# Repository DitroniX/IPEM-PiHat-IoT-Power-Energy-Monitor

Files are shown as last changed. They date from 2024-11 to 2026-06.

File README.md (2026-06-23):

# IPEM PiHat and IPEM PiHat Lite | ATM90E36 IoT Mains Power Energy Monitors

**Supporting STEM Electronic Internet of Things & Home Automation Technology for Smart Energy Monitoring**

DitroniX WiKi Pages (https://github.com/DitroniX/IPEM-PiHat-IoT-Power-Energy-Monitor/wiki)
DitroniX Discussions (https://github.com/DitroniX/IPEM-PiHat-IoT-Power-Energy-Monitor/discussions)
Compare DitroniX Mains Power IoT Energy Monitor Options

[**For Latest Project Updates - Click Here**](https://github.com/DitroniX/IPEM-PiHat-IoT-Power-Energy-Monitor/tree/main?tab=readme-ov-file#updates)

## Welcome to IPEM PiHat

The **IPEM PiHat** and **IPEM PiHat Lite,** are Mains AC Power Energy Monitor boards, which are designed to be used alongside Raspberry Pi, and similar single board computers.

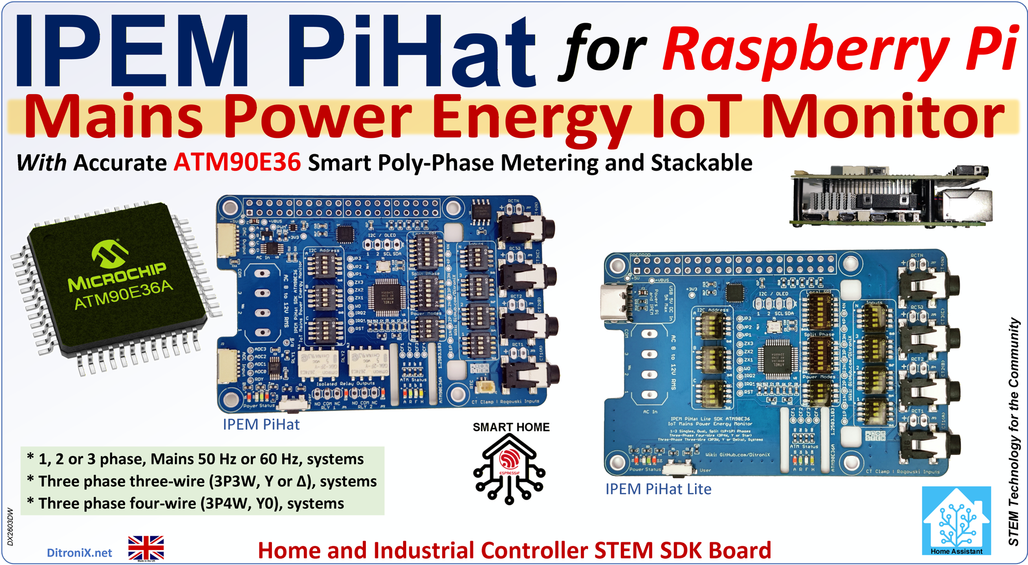
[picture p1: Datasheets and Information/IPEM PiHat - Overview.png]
IPEM PiHat


### What is a Power Energy Monitor?

A power energy monitor is a device that safely samples the [AC Voltage, and Current flow](https://github.com/DitroniX/IPEM-Plus-ESP32-C5-LoRa-LoRaWAN-IoT-Mains-Power-Energy-Monitor/wiki/What-is-a-Power-Energy-Monitor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), from one, or more, electrical phases, and from this, derives a range of accurate mains power measurements which can then be used for smart metering, or energy monitoring purposes.

These individual measurements can then be extrapolated into a range of useful real-time data such as total RMS Power, Active, Re-Active Power, Harmonic Power, Power Factor, Phase Angles, Frequency, etc.

This real-time data can then be sent via Wi-Fi or Ethernet, through to IoT Home and Industrial Energy Monitoring systems like [Home Assistant](https://www.home-assistant.io/docs/energy/).

## Variants

Two variants of IPEM PiHat are available.

 - IPEM PiHat 
	 - Full board with ATM90E36, DS3231SN RTC, Relays, 
 - IPEM PiHat Lite
	 - ATM90E36, Stackable

[Full Comparison Table.](https://github.com/DitroniX/IPEM-PiHat-IoT-Power-Energy-Monitor/wiki/Comparison-Table)

Based on the popular https://github.com/DitroniX/IPEM-IoT-Power-Energy-Monitor, the **IPEM PiHat** takes both IPEC and IPEM to another level via the Raspberry Pi.
IPEM PiHat 

#### IPEM Plus

The **IPEM PiHat** also has a new big brother called [IPEM Plus](https://github.com/DitroniX/IPEM-Plus-ESP32-C5-LoRa-LoRaWAN-IoT-Mains-Power-Energy-Monitor).  This is an ESP32-C5 and LoRa based IoT Mains Power Energy Monitor, for Standalone or Integrated Remote Projects.

## Board Views

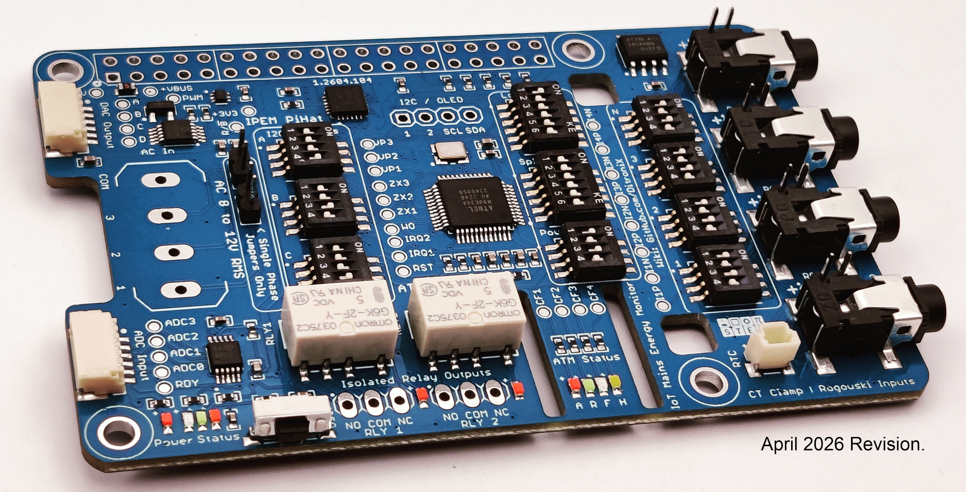
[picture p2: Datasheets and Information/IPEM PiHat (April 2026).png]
IPEM PiHat (April 2026)


IPEM PiHat

IPEM PiHat Lite

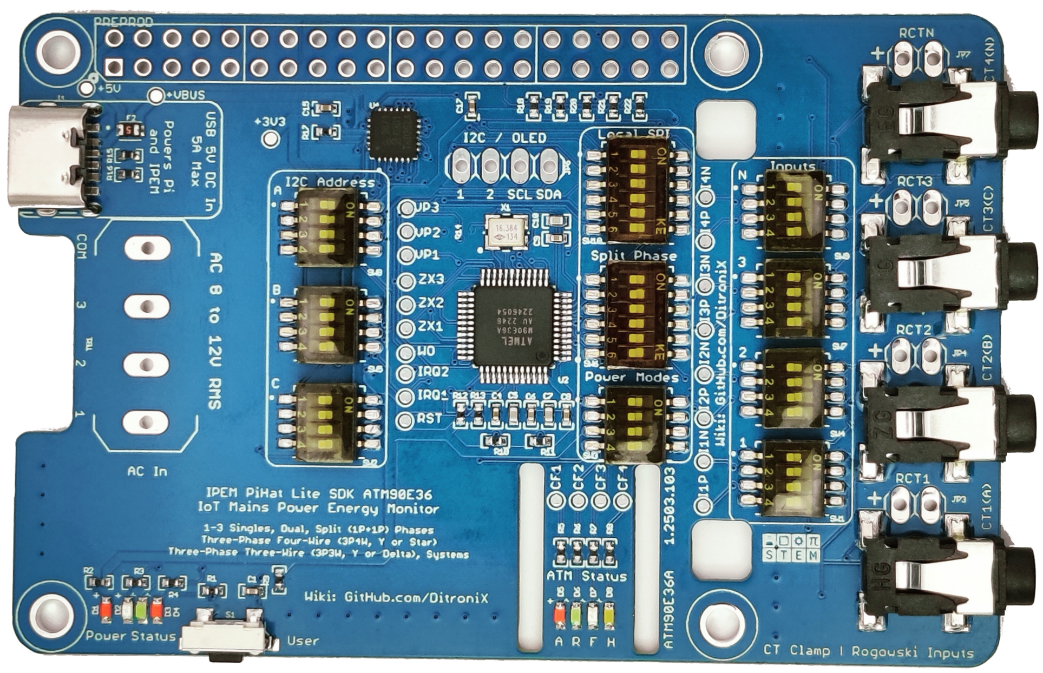
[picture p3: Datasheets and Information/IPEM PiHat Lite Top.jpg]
IPEM PiHat Lite


## ATM90E36 Mains Energy Metering and Monitoring 

### What is the ATM90E36 device?

The heart of the IPEM boards is the Microchip  ATM90E36. These are high-performance and accurate AC mains energy metering devices for:

-   Single phase
-   Two phase
-   Dual phase
-   Split phase
-   Three-phase four-wire (3P4W, Y0)
-   Three-phase three-wire (3P3W, Y or Δ), systems.

The ATM90 device is used in a range of premises and applications including:

-   Smart Meters
-   EV Charging
-   Homes
-   Education
-   Offices
-   Commercial
-   Factories6
-   Farms
-   Greenhouses
-   Factories
-   Industry
-   Solar Farms
-   Wind Farms
-   Off Grid Systems

The IPEM PiHat core is the [ATM90E36A](https://www.microchip.com/en-us/product/atm90e36a) which is used around the world in power monitoring instruments that also need to measure voltage, current, THD, DFT and mean power.

The IPEM boards requires little, to no, calibration and is easy to setup. You can use the ATM90E32 code for the standard functionality, with updated register values.

As the IPEM boards only safely sample the AC via a low voltage transformer, you are able to monitor varying AC (RMS) voltage mains around the World, such as:

-   USA and Canada which typically is 120 V or 230 V @ 60 Hz
    -   With ranges around 114 V to 126 V
-   Europe and UK which typically is 230 V @ 50 Hz
    -   With ranges around 216 V to 253 V
-   Japan which typically is 100 V @ 50 Hz or 60 Hz
    -   Eastern Japan is 50 Hz, and western Japan is 60 Hz
-   Should you wish to know more, see this [Wiki](https://en.wikipedia.org/wiki/Mains_electricity_by_country)

-------------------------------------------------------------------

**Board Addressing**
   
The IPEM PiHat boards uses SPI as a means of data communication, with an I2C expander to provide individual GPIO functionality to each ATM90E36.

Following design thoughts prior to finalising the production board, the following improvements have been added.

Change from OneWire to using a two wire I2C Expander. This provides 64 individual addresses, so essentially 64 stacked IPEM's (although this is theoretical).

The design improvement is a much more sensible route as you now assign a fixed address to each board using a DIP switch. This also makes it so much easier is field and with software support and configuration.

The unique design will allow up to a max of:

* 1 x IPEM PiHat + 63 x IPEM PiHat Lite's

or

* 64 x IPEM PiHat Lite's
   
 **CT Clamps and Rogowski Current Transformer**
 
The original IPEM design provided for using the  YHDC SCT-013 100A-50mA.

The updated IPEM PiHat and IPEM PiHat Lite production design, now allows for either use of CT Clamps, and/or Rogowski Current Transformers.  This allows for a wider spectrum of current ranges and cable sizes to be monitored.

 - CT Clamps are the main stream safe and easy method to monitor currents from the mains tails or consumer unit circuits.
   
 - Rogowski Current Transformers are typically for very high currents, or specialised current monitoring.

IPEM Raspberry Pi PiHat ATM90E36 Energy Monitor 

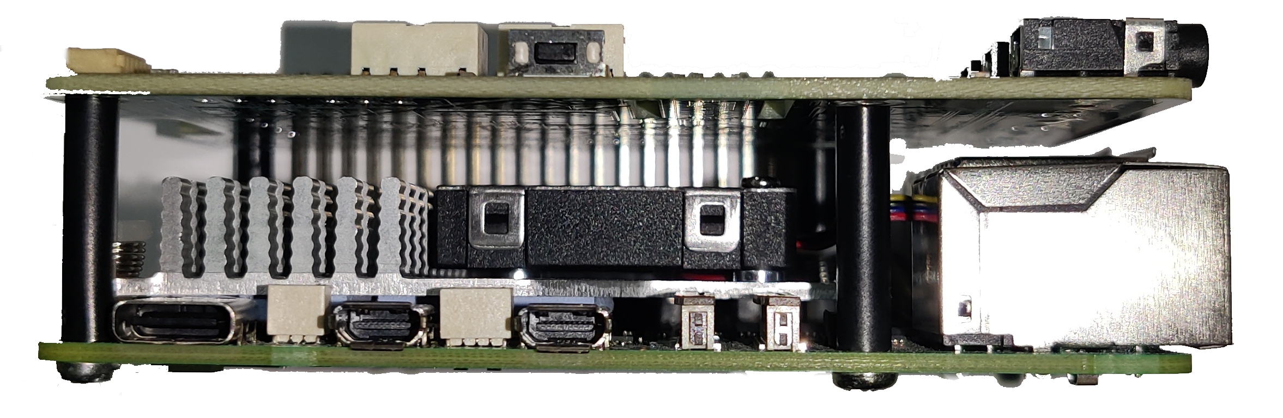
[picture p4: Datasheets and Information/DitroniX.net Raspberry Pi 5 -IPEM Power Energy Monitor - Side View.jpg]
IPEM PiHat - Beta Preview

IPEM Raspberry Pi PiHat ATM90E36 Energy Monitor 

The IPEM Raspberry Pi PiHat ATM90E36 IoT Power Energy Monitor SDK contains all of the IPEM (ESP32) functionality and includes the ATM90E36.  It then adds the ADC and DAC functionality of IPEC and IPEX (ESP32) boards.

The ATM90E36 contains all of the ATM90E32 functions plus additional functionality.

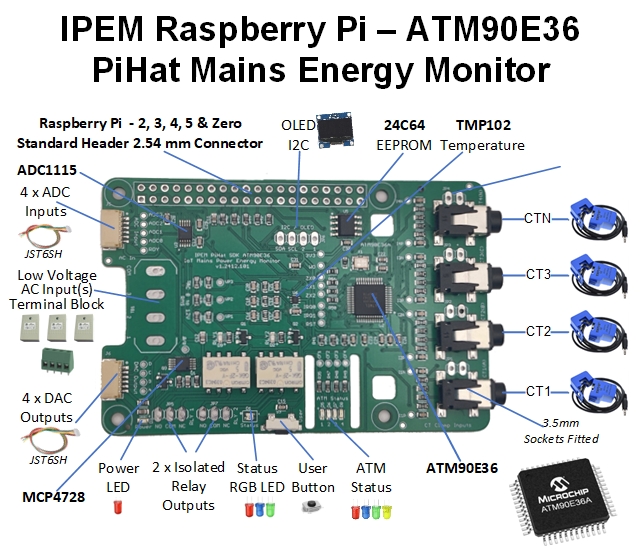
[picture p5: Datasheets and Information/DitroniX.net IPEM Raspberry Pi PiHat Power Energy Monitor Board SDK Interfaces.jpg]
IPEM PiHat - Beta Overview


**Overview**
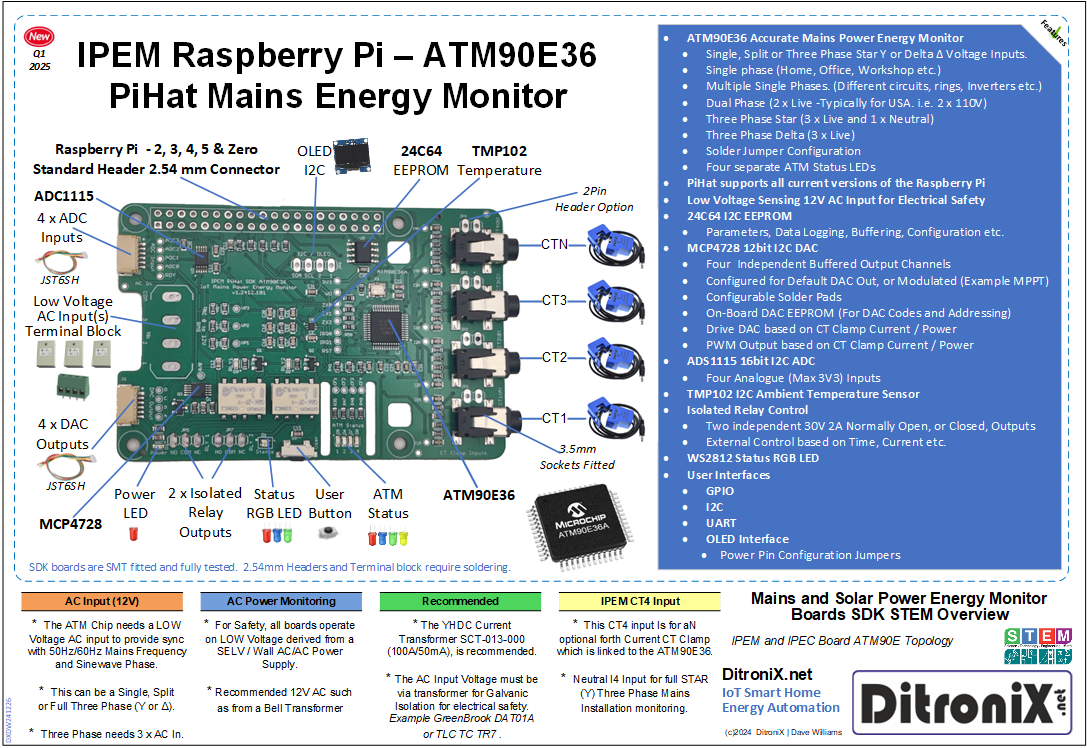
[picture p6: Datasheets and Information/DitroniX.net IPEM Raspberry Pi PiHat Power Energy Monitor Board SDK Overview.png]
IPEM PiHat - Beta Overview


**Example Stack-up**
PiHats Stacked

[3D Files](https://github.com/DitroniX/IPEM-PiHat-IoT-Power-Energy-Monitor/tree/main/Enclosure%203D)

Example Stacked Render
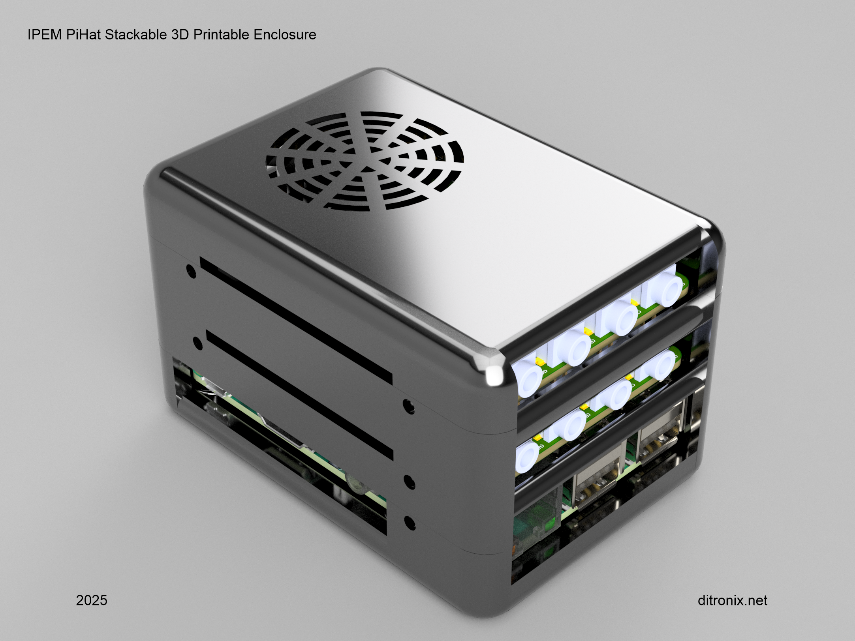
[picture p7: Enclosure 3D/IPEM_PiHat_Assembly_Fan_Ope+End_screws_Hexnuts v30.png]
Example IPEM PiHat Enclosure Render


**Mains Monitoring Options**

All my boards are designed to be safe and easy to use - with NO live parts or dangerous exposed voltages.

Both the **IPEM PiHat** and **IPEM PiHat Lite** are capable of monitoring a number of variations in energy monitoring systems.

 - Single phase (Home, Office etc.) 
 - Multiple Single Phases.  (Different circuits or home/office rings, Inverters etc.) 
 - Dual Phase (2 x Live -Typically for USA.  i.e. 2 x 110V) 
 - Three Phase Star (3 x Live and 1 x Neutral) 
 - Three Phase Delta (3 x Live)

## Top Level Features:

IPEM PiHat is available in two variants:

* IPEM PiHat
* IPEM PiHat Lite

A comparison table is available [Comparison Table](https://github.com/DitroniX/IPEM-PiHat-IoT-Power-Energy-Monitor/wiki/Comparison-Table)

-   **Compact**  and  **Flexible Design**  SDK Board
    -   All connections are  **low voltage**, for  **safe operation**
    -   **Easy to interface**
    -   Designed to fit on a Raspberry Pi
    -   Designed to easily Interface other MCUs
-    **ATM90E36**  Energy Monitor
        - Measures Currents
            -   Single phase
            -   Two phase
            -   Dual phase
            -   Split phase
            -   Three-phase four-wire (3P4W, Y0)
            -   Three-phase three-wire (3P3W, Y or Δ), systems.
        - 3 x Phases Line CT Clamp Input
            -   Example YHDC SCT013000
        - 1 x Phase Neutral CT Clamp
            -   Example YHDC SCT013000
            -   Only Required for Three-phase four-wire (3P4W)
        - 3 x Voltage Inputs (AC RMS)
            - Single Phases use same AC Input on all three
            - Three Phase use separate AC Input on each
        - DMA Mode (Logging via SPI)
            - Power Modes Settings
            - Auto DMA selection option via GPIO
            - SPI Interface
-   **PCA9671**  GPIO Expander
    -   I2C GPIO Expander
    -   Up to 64 Addresses
    -   Allows Stacking of IPEM PiHat Lite
    -   Controls the ATM90E36 /CS and GPIO
    -   I2C Interface
-   **DS3231**  RTC
    -   Accurate Real Time Clock
    -   Battery Back Up Option
    -   I2C Interface
-   **24C64**  EEPROM
    -   Parameter Settings
    -   Logging
    -   I2C Interface
 - **MCP4728** DAC
	 - 12bit I2C DAC
	 - Four Independent Buffered Output Channels
	 - Configured for Default DAC Out, or Modulated (Example MPPT)
		 - Configurable Solder Pads
	 - On-Board DAC EEPROM (For DAC Codes and Addressing)
	 - Can be configured to drive DAC based on CT Clamp Current / Power
    -   I2C Interface
 - **ADS1115** ADC
	 - 16bit I2C DAC 
	 - Independent Analogue Inputs
		 - 4 x Single Ended
		 - 2 x Differential Pairs
    -   I2C Interface
-   **OLED I2C**
    -   I2C Interface
    -   OLED I2C Connector
        -   Configurable Power Pins
-   **AC Low Voltage**  Input (for Safety)
    -   Power safely derived from a SELV / Wall AC/AC Power Supply
        -   8 to 12V AC RMS
        -   Examples GreenBrook DAT01A or TLC TC TR7
-   **TMP102** Temperature 
    -   Digital Ambient Temperature Monitor
    -   I2C Interface
-   **Isolated Outputs**
    -   Two Relays for Isolated NC or NO outputs
    -   Max 2A 30V DC
    -   Interfaces to GPIO Expander
-   **Programmable Button** User  
    -   User General Use
    -   Interfaces to GPIO Expander
-   **Solder Pads** User  
    -   User Configuration General Use
    -   2 x Solder Pads
    -   Interfaces to GPIO Expander
-   **RGB Status LED** User  
    -   User Configurable
    -   Interfaces to GPIO Expander
-   **Power LED**
    -   On 3V3
-   **ATM CT LEDs**
    -   CF1 - Active
    -   CF2 - ReActive
    -   CF3 - Fundamental
    -   CF4 - Harmonic
-   **IPEM PiHat Power**
    -   Designed to take 5V power from Raspberry Pi Header
    -   Internal 5V to 3V3 LDO Power Supply
-   **IPEM PiHat Lite Power**
    -   Designed to take 5V power from Raspberry Pi Header
    -   Internal 5V to 3V3 LDO Power Supply
    -   Can be powered via Type C UCB
	    - This also feeds 5V to Pi Header (Raspberry Pi), and other stacked PiHat boards.
-   **PCB** designed the same size as a Raspberry Pi.
    -   Also allows for the optional OLED display to be included, or not.
    -   Size**  85 mm x 55 mm
------------

**In The Box - [Ship Kit](https://github.com/DitroniX/IPEM-PiHat-IoT-Power-Energy-Monitor/wiki/IPEM-PiHat-Ship-Kit)**

In the Box for IPEM PiHat

 - 1 x IPEM PiHat 	
	 - SMD (Surface Mounted Components) Populated / Tested.
	 - 1 x Terminal Blocks (4 Pin Not Soldered) 
	 - 1 x 40 Pin 2x20 Header (Not Soldered) 
	 - 4 x Sets of M2.5 x 18 Pillar, Pan Heads and Nuts 
	 - 2 x 6 pin JST Pigtail (Open Ended for ADC/DAC) 
	 - 1 x Strip of straight pin header (Not Soldered) 
	 - 1 x 4 pin header socket (Not Soldered) 
	 - 1 x Complimentary screwdriver

In the Box for IPEM PiHat Lite

 - 1 x IPEM PiHat Lite	
	 - SMD (Surface Mounted Components) Populated / Tested.
	 - 1 x Terminal Blocks (4 Pin Not Soldered) 
	 - 1 x 40 Pin 2x20 Header (Not Soldered) 
	 - 4 x Sets of M2.5 x 15 Pillar, Pan Heads and Nuts 
	 - 1 x Strip of straight pin header (Not Soldered) 
	 - 1 x 4 pin header socket (Not Soldered) 
	 - 1 x Complimentary screwdriver

Example Ship Kit

IPEM PiHat Lite

## Current Clamps

You will need to provide a CT Current Clamp. Ideally a YHDC SCT-013-000.  

A Rogowski Current Transformer maybe used for very high currents or specialist measurements.

## Code

All test code is OPEN SOURCE and although is is not intended for real world use, it may be freely used, or modified as needed. It is distributed on an "AS IS" BASIS, WITHOUT WARRANTIES OR CONDITIONS OF ANY KIND, either express or implied.

## **Purchase**
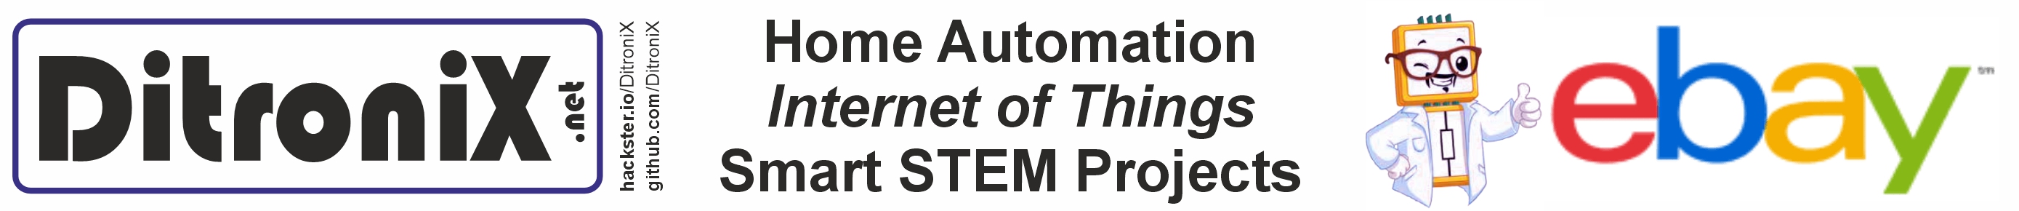
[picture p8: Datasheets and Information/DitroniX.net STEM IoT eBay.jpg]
Display-Type-B (https://www.ebay.co.uk/usr/ditronixuk)


Our STEM SDK boards and accessories are available from our online shops on [eBay](https://www.ebay.co.uk/usr/ditronixuk) 

## Updates:

 - 26-05-03 - More IPEM PiHat Lite boards in production.  Estimated later this month.
 - 26-04-22 - Boards back in Stock.  IPEM PiHat for Single Phase, [two jumpers have been included](https://github.com/DitroniX/IPEM-PiHat-IoT-Power-Energy-Monitor/wiki/Single-Phase-Configuration) in the April 2026 release of the board.
 - 26-04-01 - IPEM PiHat Updated to include Jumpers for Single Phase. New production run in progress.  Stock due mid April.
 - 25-06-15 - [FLiX PiHat](https://github.com/DitroniX/FLIX-DitroniX-Power-Energy-Monitors-Firmware) Development Code Firmware Beta released
 - 25-04-24 - 3D Render and STL files released to build a stackable enclosure. [ThingiVerse](https://www.thingiverse.com/thing:7019134)
 - 25-04-15 - 3D Render and STL files released to build a stackable enclosure.  [3D Files](https://github.com/DitroniX/IPEM-PiHat-IoT-Power-Energy-Monitor/tree/main/Enclosure%203D)
 - 25-04-14 - Kickstarter fulfillment complete. Both version of the boards are now available for purcase on eBay.
 - 25-04-08 - Boards Tested and pleased to share, that they are now being shipped to all Kickstarter backers.  Many thanks to all the support on this project.
 - 25-04-02 - Production boards (Both Variants), in Production QA.  Delivery to me by early next week.  Final Check on Production boards upon arrival and then shipping to KickStarter Backers! Then added to eBay. Excellent.
 - 25-03-26 - Preproduction testing complete and Production boards (Both Variants), ordered.
 - 25-03-21 - Excellent news in that testing is almost complete.  This is a range of comprehensive testing of the both boards, various electrical testing and safety compliance.  Taken a few days longer than planned but all is good.  Production still planned for this month.
 - 25-03-14 - Testing the Preproduction boards. See this [YouTube Update](https://www.youtube.com/watch?v=YpOppCA2oIU&ab_channel=DitroniX)
 - 25-03-11 - Preproduction boards have arrived and now going through testing, with updates to Wiki on-route.
 - 25-03-05 - Prep6roduction boards being finalised in SMT manufacture.  Once these arrive, they can be fully tested in preparation for the production boards to be ordered.
 - 25-02-28 - All components are now available. Preproduction boards ordered and currently in Data Preparation.
 - 25-02-27 - Final BOM components are expected to arrive today and then the Preproduction boards will be immediately ordered.
 - 25-02-17 - Awaiting full BOM STK following Chinese NY Holiday.
   Preproduction boards can then be ordered/tested.
 - 25-02-14 - Preproduction IPEM PiHat and IPEM PiHat Lite boards are
   being ordered.
 - 25-02-05 - Example 3D renders of pre-production boards. Comparison
   Chart. 
 - 25-02-02 - Work now continues in supporting documentation, Wiki and
   software examples code.
 - 25-01-23 - Pre-production schematics have been finalised and the
   boards routed.
 - 25-01-17 - Collated feedback. Finalise Pre-production design of both IPEM
   PiHat and IPEM PiHat Lite.

As we steam ahead to production, just wanted to share some photos of the final pre-production version of the two great looking boards.

## **Further Information**

Additional information, and other technical details on this project, maybe found in the related repository pages.

**Repository Folders**

 - **Code** *(Code examples for Raspberry Pi, Arduino  IDE and PlatformIO)*
 -  **Datasheets and Information** *(Component Datasheets, Schematics, Board Layouts, Photos, Technical Documentation)*
 - **Certification** *(Related Repository Project or Part, Certification Information)*

**Repository Tabs**

 - **Wiki** *(Related Repository Wiki pages and Technical User Information)*
 - **Discussions** *(Related Repository User Discussion Forum)*
 - **Issues** *(Related Repository Technical Issues and Fixes)*

***

We value our Customers, Users of our designs and STEM Communities, all over the World . Should you have any other questions, or feedback to share to others, please feel free to:

* Visit the related [Project](https://github.com/DitroniX?tab=repositories) *plus the related* **Discussions** and **Wiki** Pages.  See tab in each separate repository.
* **Project Community Information** can be found at https://www.hackster.io/DitroniX
* [DitroniX.net Website - Contact Us](https://ditronix.net/contact/)
* **Twitter**: [https://twitter.com/DitroniX](https://twitter.com/DitroniX)
* [Supporting the STEM Projects - BuyMeACoffee](https://www.buymeacoffee.com/DitroniX)
*  **LinkedIN**: [https://www.linkedin.com/in/g8puo/](https://www.linkedin.com/in/g8puo/)

***Dave Williams, Maidstone, UK.***

Electronics Engineer | Software Developer | R&D Support | RF Engineering | Product Certification and Testing | STEM Ambassador

## STEM

**Supporting [STEM Learning](https://www.stem.org.uk/)**

Life is one long exciting learning curve, help others by setting the seed to knowledge.



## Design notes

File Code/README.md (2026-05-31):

**IPEM PiHat and IPEM PiHat Lite | ATM90E36 IoT Power Energy Monitor SDK**

------------

## See also FliX Development Code - IPEM PiHat - ESPuno Pi Zero

[https://github.com/DitroniX/FLIX-DitroniX-Power-Energy-Monitors-Firmware ](https://github.com/DitroniX/FLIX-DitroniX-Power-Energy-Monitors-Firmware)

## Remember to Solder the Pi Header!
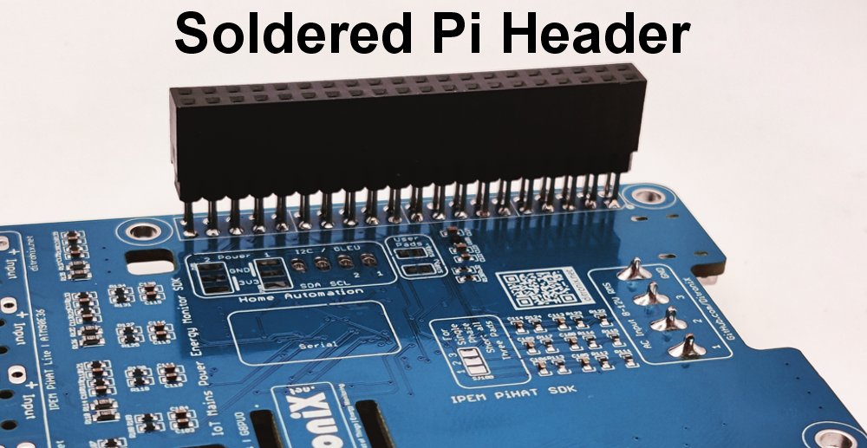
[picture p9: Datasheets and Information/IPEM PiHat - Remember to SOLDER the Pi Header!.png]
IPEM PiHat - Remember to SOLDER the Pi Header!


This folder will contain expanding example and full test code.

  Remember!
  This test code is OPEN SOURCE and formatted for easier viewing.  Although is is not intended for real world use, it may be freely used, or modified as needed.
  It is distributed on an "AS IS" BASIS, WITHOUT WARRANTIES OR CONDITIONS OF ANY KIND, either express or implied.

## **Further Information**

Additional information, and other technical details on this project, maybe found in the related repository pages.

**Repository Folders**

 - **Code** *(Code examples for Raspberry Pi, Arduino  IDE and PlatformIO)*
 -  **Datasheets and Information** *(Component Datasheets, Schematics, Board Layouts, Photos, Technical Documentation)*
 - **Certification** *(Related Repository Project or Part, Certification Information)*

**Repository Tabs**

 - **Wiki** *(Related Repository Wiki pages and Technical User Information)*
 - **Discussions** *(Related Repository User Discussion Forum)*
 - **Issues** *(Related Repository Technical Issues and Fixes)*

***

We value our Customers, Users of our designs and STEM Communities, all over the World . Should you have any other questions, or feedback to share to others, please feel free to:

* Visit the related [Project](https://github.com/DitroniX?tab=repositories) *plus the related* **Discussions** and **Wiki** Pages.  See tab in each separate repository.
* **Project Community Information** can be found at https://www.hackster.io/DitroniX
* [DitroniX.net Website - Contact Us](https://ditronix.net/contact/)
* **Twitter**: [https://twitter.com/DitroniX](https://twitter.com/DitroniX)
* [Supporting the STEM Projects - BuyMeACoffee](https://www.buymeacoffee.com/DitroniX)
*  **LinkedIN**: [https://www.linkedin.com/in/g8puo/](https://www.linkedin.com/in/g8puo/)

***Dave Williams, Maidstone, UK.***

Electronics Engineer | Software Developer | R&D Support | RF Engineering | Product Certification and Testing | STEM Ambassador

## STEM

**Supporting [STEM Learning](https://www.stem.org.uk/)**

Life is one long exciting learning curve, help others by setting the seed to knowledge.



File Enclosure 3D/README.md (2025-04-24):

**IPEM PiHat and IPEM PiHat Lite | ATM90E36 IoT Power Energy Monitor SDK**

This folder contains 3D related files for printing a stackable enclosure for the IPEM PiHat and IPEM PiHat Lite.

Many thanks to *TwoLeftFeet* for the kind contribution.

Example Stacked Render
Example IPEM PiHat Enclosure Render

**Updates**

250424 Files added to ThingiVerse https://www.thingiverse.com/thing:7019134

250415 Initial Release - IPEM_PiHat_Assembly_Fan_Ope+End_screws_Hexnuts v30

250311 Mechanical development and [Alpha release](https://github.com/DitroniX/IPEM-PiHat-IoT-Power-Energy-Monitor/wiki/Stackable-Enclosure-3D) of enclosure

## **Further Information**

Additional information, and other technical details on this project, maybe found in the related repository pages.

**Repository Folders**

 - **Code** *(Code examples for Raspberry Pi, Arduino  IDE and PlatformIO)*
 -  **Datasheets and Information** *(Component Datasheets, Schematics, Board Layouts, Photos, Technical Documentation)*
 - **Certification** *(Related Repository Project or Part, Certification Information)*

**Repository Tabs**

 - **Wiki** *(Related Repository Wiki pages and Technical User Information)*
 - **Discussions** *(Related Repository User Discussion Forum)*
 - **Issues** *(Related Repository Technical Issues and Fixes)*

***

We value our Customers, Users of our designs and STEM Communities, all over the World . Should you have any other questions, or feedback to share to others, please feel free to:

* Visit the related [Project](https://github.com/DitroniX?tab=repositories) *plus the related* **Discussions** and **Wiki** Pages.  See tab in each separate repository.
* **Project Community Information** can be found at https://www.hackster.io/DitroniX
* [DitroniX.net Website - Contact Us](https://ditronix.net/contact/)
* **Twitter**: [https://twitter.com/DitroniX](https://twitter.com/DitroniX)
* [Supporting the STEM Projects - BuyMeACoffee](https://www.buymeacoffee.com/DitroniX)
*  **LinkedIN**: [https://www.linkedin.com/in/g8puo/](https://www.linkedin.com/in/g8puo/)

***Dave Williams, Maidstone, UK.***

Electronics Engineer | Software Developer | R&D Support | RF Engineering | Product Certification and Testing | STEM Ambassador

## STEM

**Supporting [STEM Learning](https://www.stem.org.uk/)**

Life is one long exciting learning curve, help others by setting the seed to knowledge.



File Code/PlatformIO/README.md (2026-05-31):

**IPEM PiHat and IPEM PiHat Lite | ATM90E36 IoT Power Energy Monitor SDK**

------------

## FliX Development Code - IPEM PiHat - ESPuno Pi Zero

## Test Jig Using ESPuno Pi Zero
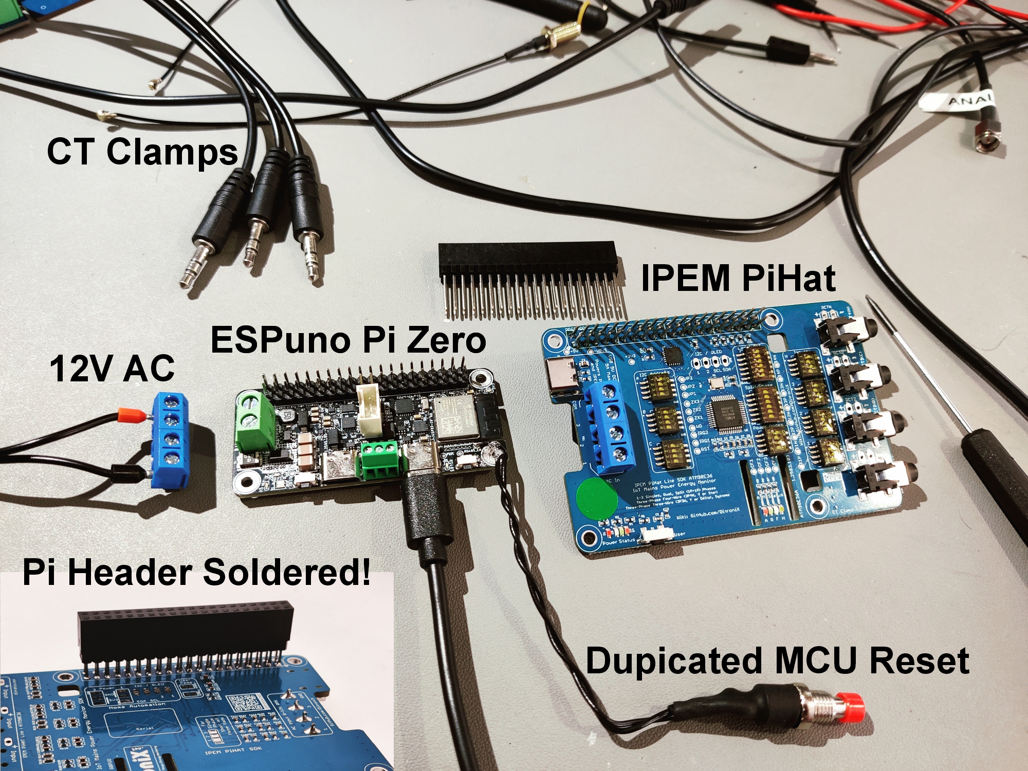
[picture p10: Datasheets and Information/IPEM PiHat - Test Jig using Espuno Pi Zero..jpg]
IPEM PiHat - Test Jig using Espuno Pi Zero.


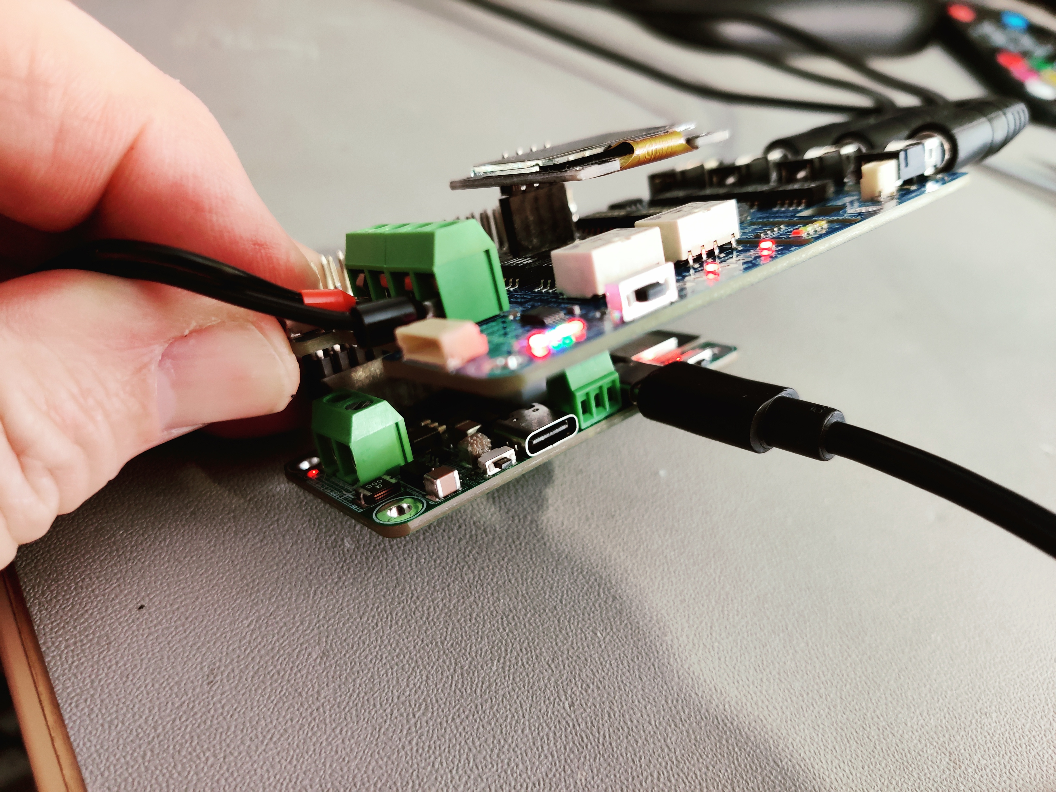
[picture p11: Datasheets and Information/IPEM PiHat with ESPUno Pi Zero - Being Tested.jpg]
IPEM PiHat with ESPUno Pi Zero - Being Tested


## Remember to Solder the Pi Header!
IPEM PiHat - Remember to SOLDER the Pi Header!

[https://github.com/DitroniX/FLIX-DitroniX-Power-Energy-Monitors-Firmware ](https://github.com/DitroniX/FLIX-DitroniX-Power-Energy-Monitors-Firmware)

This folder will contain expanding example and full test code.

  Remember!
  This test code is OPEN SOURCE and formatted for easier viewing.  Although is is not intended for real world use, it may be freely used, or modified as needed.
  It is distributed on an "AS IS" BASIS, WITHOUT WARRANTIES OR CONDITIONS OF ANY KIND, either express or implied.

## **Further Information**

Additional information, and other technical details on this project, maybe found in the related repository pages.

**Repository Folders**

 - **Code** *(Code examples for Raspberry Pi, Arduino  IDE and PlatformIO)*
 -  **Datasheets and Information** *(Component Datasheets, Schematics, Board Layouts, Photos, Technical Documentation)*
 - **Certification** *(Related Repository Project or Part, Certification Information)*

**Repository Tabs**

 - **Wiki** *(Related Repository Wiki pages and Technical User Information)*
 - **Discussions** *(Related Repository User Discussion Forum)*
 - **Issues** *(Related Repository Technical Issues and Fixes)*

***

We value our Customers, Users of our designs and STEM Communities, all over the World . Should you have any other questions, or feedback to share to others, please feel free to:

* Visit the related [Project](https://github.com/DitroniX?tab=repositories) *plus the related* **Discussions** and **Wiki** Pages.  See tab in each separate repository.
* **Project Community Information** can be found at https://www.hackster.io/DitroniX
* [DitroniX.net Website - Contact Us](https://ditronix.net/contact/)
* **Twitter**: [https://twitter.com/DitroniX](https://twitter.com/DitroniX)
* [Supporting the STEM Projects - BuyMeACoffee](https://www.buymeacoffee.com/DitroniX)
*  **LinkedIN**: [https://www.linkedin.com/in/g8puo/](https://www.linkedin.com/in/g8puo/)

***Dave Williams, Maidstone, UK.***

Electronics Engineer | Software Developer | R&D Support | RF Engineering | Product Certification and Testing | STEM Ambassador

## STEM

**Supporting [STEM Learning](https://www.stem.org.uk/)**

Life is one long exciting learning curve, help others by setting the seed to knowledge.



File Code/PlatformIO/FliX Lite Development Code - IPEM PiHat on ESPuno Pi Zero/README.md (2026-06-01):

Dave Williams, DitroniX 2019-2026 (ditronix.net)

**Development Code - WORK-IN-PROGRESS - NOT FINALASED!!!**

Initial Draft Release: 15th June 2025
Updated 30th May 2026

### **Purpose of Code**

The purpose of this firmware code is to drive an IPEM PiHat, or IPEM PiHat Lite, Energy Monitoring Board from an ESP based MCU, rather than from a Raspberry Pi.

The code was developed essentially as an internal testing 'tool', which exercises the IPEM PiHat boards during R&D, bring up and testing.

## Test Jig Using ESPuno Pi Zero
IPEM PiHat - Test Jig using Espuno Pi Zero.

IPEM PiHat with ESPUno Pi Zero - Being Tested

## Remember to Solder the Pi Header!
IPEM PiHat - Remember to SOLDER the Pi Header!

**Development**

This code was developed and tested on the below hardware:

 - [IPEM PiHat](https://github.com/DitroniX/IPEM-PiHat-IoT-Power-Energy-Monitor), or [IPEM PiHat Lite](https://github.com/DitroniX/IPEM-PiHat-IoT-Power-Energy-Monitor)
 - [ESPuno Pi Zero](https://github.com/DitroniX/ESPuno-Pi-Zero_WiFi-BT-Zigbee-Thread-60V)

### **Top Level Overview**

This firmware is a work-in-progress stripped down and updated version of the original FLiX code that resides in https://github.com/DitroniX/FLIX-DitroniX-Power-Energy-Monitors-Firmware

The purpose of this test code is to cycle through the various main functions of the boards, as part of board bring up testing.

This code has expanded way past it's original IPEM bring-up task and is now quite comprehensive. It can now be, as is, used for both bring-up, final use and publishing.

A number of software switches are used, throughout. The defaults variables and switches are contained in config.h

**Energy Monitoring Board**

The FLiX firmware core driver is for the [Atmel  ATM90E36](https://www.microchip.com/en-us/product/atm90e36a), which is a High Performance and Accurate Mains Energy Monitoring device, as used on the IPEM Series of IoT Power Energy Monitor SDK boards.

Communications to the ATM90E36 is via SPI.   This firmware allows SPI Chip Select via either GPIO from the ESP32-C6, or software control via the GPIO Expander.  The [IPEM PiHat configuration](https://github.com/DitroniX/IPEM-PiHat-IoT-Power-Energy-Monitor/wiki/DIP-Switch-Configuration) being used to control this.

**Modules**

The firmware currently incorporates the following 'modules'

 - Main
	 - Hardware
 - [Devices](https://github.com/DitroniX/IPEM-PiHat-IoT-Power-Energy-Monitor/wiki/Devices)
	 - ATM90E36 (Energy Monitoring)
	 - [PCA9671](https://github.com/DitroniX/IPEM-PiHat-IoT-Power-Energy-Monitor/wiki/GPIO-Configuration-%E2%80%90-IPEM-PiHat) (I2C GPIO Expander)
	 - OLED (Driver for SSD1306 I2C Display - Default 0.96")
	 - TMP102 (I2C Temperature Sensor)
	 - DS3231 (I2C RTC)
	 - ADS1115 (I2C ADC)
	 - 24C64 (EEPROM)
 - Publishing
	 - Wi-Fi
		 - MQTT
		 - Domoticz

### **Compiling and Flashing**
This code has been developed within the Microsoft VS Code and [Platform IO](https://github.com/DitroniX/ESPuno-Pi-Zero_WiFi-BT-Zigbee-Thread-60V/wiki/PlatformIO-Configuration) environment IDE.

**Files**

The *platformio.ini* contains the configuration for the ESP32-C6 based ESPuno Pi Zero board, along with the prerequisite third party library dependencies.

The *config.h* contains the main user variables, software switches and configuration parameters

**Logging**
A comprehensive serial log output is included in the firmware.  Examples are included in the root of the code folder.

  ### **Configuration**

This version of firmware code has the setups for bring-up testing of the board:  

- AUTO Configuration of IPEM PiHat ATM90E36 variant:
	- IPEM PiHat
	- IPEM PiHat Lite
- Connected to an ESPuno Pi Zero ESP32-C6 MCU

- DIP Switches configured as per [Defaults](https://github.com/DitroniX/IPEM-PiHat-IoT-Power-Energy-Monitor/wiki/DIP-Switch-Configuration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)

- Multi-Voltage Input (ATM_SINGLEVOLTAGE true)

- Split-Phase USA - Disabled (ATM_SPLITPHASE false)

- Display of Board Configuration (EnableDisplayBoardConfiguration true)

- Loop Refreshing Terminal Output (EnableBasicLoop false) - Display Info ONCE uppon Reset.

- Value Outputs are filtered through a Software Noise Filter / Comparator / Squelch (EnableNoiseFilterSquelch true)

- OLED 0.96" Display SSD1306 128x32. (EnableOLEDLoop true)

- Board Location and Firmware Version to OLED and Serial Monitor

- Wi-Fi (DisableWiFi false) Requires SSID/PWD to auto enable

- MQTT Publishing - Disabled (EnableMQTT false)

- Domoticz Publishing - Disabled (EnableDomoticz false)

- IP Address Defaults to DHCP. Static IP Address Configuration in WiFi-OTA.h

### **Calibration**

This version of firmware has been designed to reduce to a minimum calibration of the ATM90E36.

**[Mains Sense Input](https://github.com/DitroniX/IPEM-PiHat-IoT-Power-Energy-Monitor/wiki/AC-Mains-Voltage-Sense-Input)**

A 50Hz or 60Hz sense signal is required in order to synchronise with the signals from the CT Clamps.  This signal is fed into the IPEM boards via a low voltage AC signal (8 to 12V AC RMS), which is typically provided, for safety reasons, via SELV mains transformer.

Most users use a Bell Transformer, such as a GreenBrook DAT01A. or TLC TC TR7. You could use a 'wall wart' type power supply but this MUST be an AC _transformer _type and NOT a switched mode.

Voltages default calculation settings are based on Single/Three Phase Voltage Inputs from a Greenbrook DAT01A (TC TR7) Transformer, set to 12V AC.

**[Current Clamps](https://github.com/DitroniX/IPEM-PiHat-IoT-Power-Energy-Monitor/wiki/Current-Clamps)**

Current measurements are taken from sensors called Current Clamps.  These can be either Current Transformer (CT), Clamps, and/or Rogowski Current Transformers.

- Current Clamp default example settings are based on SCT-013-000 100A/50mA.

- Current Clamps CT1, CT2 and CT3 are connected to the ATM90E36. Calibration requirements should be minimal and board ready to use.

- AC Voltage Inputs V1, V2 and V3 are connected to the ATM90E36. Calibration requirements should be minimal and board ready to use.

- Current Clamp CT4 is only needed when measuring Three-phase four-wire (3P4W, Y0), installations.

**WiFi and OTA Updates**

- Setup WiFi

- Configure Multi-WiFi SSID/PWD

- Setup Optional Static IP address and Gateway (DHCP or Static)

- Setup Preferred Hostname

- Setup Serial Device over IP (Used for OTA)

- Display WiFI Signal Meter

**MQTT**

- Setup connection to MQTT Broker / Home Automation

- Configure Required Values to Publish to MQTT Broker

**DOMOTICZ**

- Setup connection to Domoticz Home Automation

- Configure Required Values to Publish to Domoticz Hardware Device Indexes

- When Publishing to Domoticz - Mute Detailed Output to Serial (Loop)

Enjoy! Dave Williams, DitroniX.net

**Remember!**

- Set the BOARD to ESP32, 'WEMOS D1 MINI ESP32' DEV Module (or similar).

- You may set the BAUD rate to 921600 to speed up flashing.

- The SDK board does NOT need external power to flash. It will take Power from the USB 5V.

- You can safely connect both USB Power and PSU AC In, at the sme time (Makes development much easier).

**Other Notes**

In the default state, upon first power up and during reset, the Green LED may be partially lit. Once programmed and the GPIO defined, the Green LED will go off after power up.

This test code is OPEN SOURCE and formatted for easier viewing. Although is is not intended for real world use, it may be freely used, or modified as needed.

It is distributed on an "AS IS" BASIS, WITHOUT WARRANTIES OR CONDITIONS OF ANY KIND, either express or implied.

**Wiki and Code Examples**

Further information, details and code examples can be found on our wiki pages on github.com/DitroniX

- https://github.com/DitroniX
- https://github.com/DitroniX/IPEM-PiHat-IoT-Power-Energy-Monitor
- https://github.com/DitroniX/IPEM-PiHat-IoT-Power-Energy-Monitor/wiki
- https://github.com/DitroniX/ESPuno-Pi-Zero_WiFi-BT-Zigbee-Thread-60V
- https://github.com/DitroniX/ESPuno-Pi-Zero_WiFi-BT-Zigbee-Thread-60V/wiki
- https://github.com/DitroniX/PGEZ-PCA9671-GPIO-Expander-Zero/wiki

### **Acknowledgements**

Base 90E32/36 register formulation is based on the original excellent ground work from Tisham Dhar, whatnick \| ATM90E36 Energy Monitor Core. This then being adapted over time where needed.

FLiX main VSCode / Platform IO base, E36 Registers/Code Merged, Adapted, Updated, Software Logic/Routines, Bring Up Firmware, Comprehensive Functions and Wi-Fi integration such as OTA, Domoticz Integration etc. by Date Williams

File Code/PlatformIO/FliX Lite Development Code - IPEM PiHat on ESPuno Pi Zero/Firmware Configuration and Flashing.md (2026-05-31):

The **IPEM** Test and Development Firmware has evolved a great deal over a short period and this Wiki page will hopefully provide some insight to it's features and options.

Rather than use the Arduino IDE, the IPEM firmware has been developed using Visual Studio Code (VSCode) and PlatformIO.  This integrating increased flexibility, ease of use and also allows for the correct libraries to be automatically installed, so making for a better overall user experience.

Originally, the purpose of '[IPEM_1_Test_Code_ATM90E32_ATM90E36](https://github.com/DitroniX/IPEM-IoT-Power-Energy-Monitor/tree/main/Code/IPEM_1_Test_Code_ATM90E32_ATM90E36)' was as a piece of test code / firmware, which cycled through the various main functions of the board, as part of board bring up testing.

As time moved on, the single code base, expanded to include various functions, which applies to all variations of IPEM.  This makes it easier to maintain and configure, irrespective of board version.

You can use this firmware for both:
* Testing (modify as needed to suit your integration requirements)
* Final Application (just configure and flash)

**IPEM Board Overview**

The main purpose of the code, is to provide an array of functionality, such as:

* Initial IPEM Board Bring Up and Hardware Test 
* Integration of functions and parameters for both ATM90E32 and ATM90E36
* Configuration of CT Clamp Inputs
	- CT1, 2 and 3 to ATM90E32 or ATM90E32
	- CT4 to ATM90E36 or ESP32 ADC
	
* Mains voltage calculations, using either:
	- Single AC Input for all three main Power readings
	- Three Phase.  Separate AC Input for all three main Power readings
	* Split Phase. Dual AC Voltage  Input for Split Voltage US Power reading
	
* Fast Setup and Installation
	
* Comprehensive [List of Variables](https://github.com/DitroniX/IPEM-IoT-Power-Energy-Monitor/wiki/IPEM-Variables-and-Functions), which ultimately translate into available readings, which can be displayed or published to Home Automation.  Domoticz, MQTT etc..  
* Integrated Domoticz Publishing (this will be expanded)
* Web Server
	- Home Page (with basic information)
	- Push OTA (Remote flashing over HTTP)
	
* OLED Display Driver
	- Directly plug in an I2C SSD1306 Display
	* Runtime Monitoring Information
	* Diagnostics

**Hardware Configuration**

The default hardware and firmware settings configuration is based on:

* Current Clamps.  Default example settings are based on the [YDHC SCT-013-000 100A/50mA](https://ditronix.net/shop/yhdc-current-transformer-sct-013-000-100a-50ma/).

* AC Voltage.  Inputs from a [Greenbrook DAT01A (TC TR7) Transformer](https://www.greenbrook.co.uk/dat01a), set to 12V AC.

**Firmware Logic**

Various software logic and switches has been included within the code, this automatically enables, and disables, various functions depending on options set.  For the time being, please do not alter these, unless you understand the implications.  

*Please keep to the below 'Firmware Configuration' settings.*

**Calibration**

Based on the above hardware configuration, calibration should be absolutely minimal, to not required.  All boards are tested using this configuration, with a fixed AC voltage source and fixed resistive loads, to three CT Clamp.

An example Serial Monitor output, can be seen at [here](https://github.com/DitroniX/IPEM-IoT-Power-Energy-Monitor/wiki/IPEM-Serial-Monitor-Example).

**Quick Flashing and Initial Test**

From the 'box', the firmware have been thoroughly tested and should open, and compile, without any issues.  

*NB. All boards will have this firmware installed by default, as is is used for production testing too.*

1) Download the '[Source Code](https://github.com/DitroniX/IPEM-IoT-Power-Energy-Monitor/tree/main/Code/IPEM_1_Test_Code_ATM90E32_ATM90E36)'
2) Open the folder from PlatformIO
3) Connect an IPEM board to the USB Port
4) Click Upload.

PlatformIO should automatically install any libraries not already installed and then connect to the IPEM board.  Once compiled (Click Upload in Status Bar), it should flash the board.

Once flashed, Open the 'Serial Monitor' (Click Serial Monitor in Status Bar), and you should see the default output from the IPEM board.  Press RESET to refresh the Serial Monitor Info.

NB.  You can also press (for 1 second), the USER BUTTON to refresh the information displayed.

**Firmware Configuration**

Now you have proven the flashing and test concept, we can now expand to the options in the source files.

* **main.cpp** {src folder}	*For the most part, these can stay as defaults.*
	* **LoopDelay**  *(Loop Delay in Seconds.  Default 1)*
	* **EnableBasicLoop** *(Display looped readings in the Serial Monitor, or leave for displaying only once per reset cycl using default of false.)*
	* **EnableDisplayBoardConfiguration**  *(Display board software configuration Information if DisplayFull is true.)*
	* **EnableOLEDLoop** *(Enables OLED Display.  Over-ride via I2C Scan.)*
	
* **ATM90E36.cpp** {src folder} *Nothing to update.*

* **IPEM_Hardware.h** {include folder}
	* **App USER**
		* Change 'LocationName', to something more descriptive, such as Home, Solar, Workshop etc.
	* **Constants USER**
		* These can be left as the defaults
	* **OLED Instance**
		* Uncomment your OLED Display.  Default is the 0.6"
		* If no OLED connected, can be left as the defaults 
	* **CT4 Energy Monitor Library Configuration**
		* These can be left as the defaults
		* Update at a later time, if using CT4 into ESP32
		
* **ATM90E36.h** {include folder} *For the most part, these can stay as defaults.*
	* **ATM90E36 device**
		* These can be left as the defaults
		* Only need to update, if using an ATM90E36		
	* **DEFINE Current Clamp Input CT4**
		* These can be left as the defaults
		* Possibly, only may need to update if using an ATM90E36		
	* **CT4 Software Configuration**
		* These can be left as the defaults
		* Possibly, only need to update if using ESP32/CT4
	* **DEFINE VOLTAGE REFERENCE**
		* Can be left as the default true
		* Change to False, only if using separate AC voltage Inputs.	
	* **DEFINE PHASE TYPE**
		* Can be left as the default false
		* Change to true, only if using split phase AC Voltage. e.g. USA					

* **WiFi-OTA.h** {include folder} *Update with your Wi-Fi Settings*
	* **Wireless Information**
		* Enter your Router/AP SSID and Password
	* **Static IP**
		* If you are using DHCP, then leave as defaults
		* If wanting a Static IP, first find a suitable address and update as needed.
			- The board will automatically set this IP upload flashing.
	* **DNS**
		* For the most parts, leave as default.
* **Domoticz.h** {include folder} *Update with your Domoticz Server Settings*
	* **Server IP**
		- Domoticz Server IP Address (Typically a Fixed Local Address)
	* **EnableDomoticz**
		- Set to true, once you have setup the Device Indexes.
	* **Domoticz Hardware Device Indexes**
		- Simply change index('s) from 0 to a 'device index number', which you want to publish.
		- A Variable list can be found [here](https://github.com/DitroniX/IPEM-IoT-Power-Energy-Monitor/wiki/Domoticz-Variables)
						
**Web Server and Push OTA**			

The Web Server will assume the IP, either via DHCP or Static, which ever you setup.

To find the IP address, it will be displayed on both the Serial Monitor and OLED Display, upon pressing board Reset.			

You have TWO pages on the Web Server.

* 'Home Page' which displays basic info on the board configuration
* 'update' which will display the ElegantOTA page
	- Simply compile your code
	- Choose *firmware.bin* file
		+ Found in IPEM_1_Test_Code_ATM90E32_ATM90E36 - DW Domoticz - OTA\.pio\build\wemos_d1_mini32\
	- ElegantOTA will then upload to the IPEM and auto reboot.

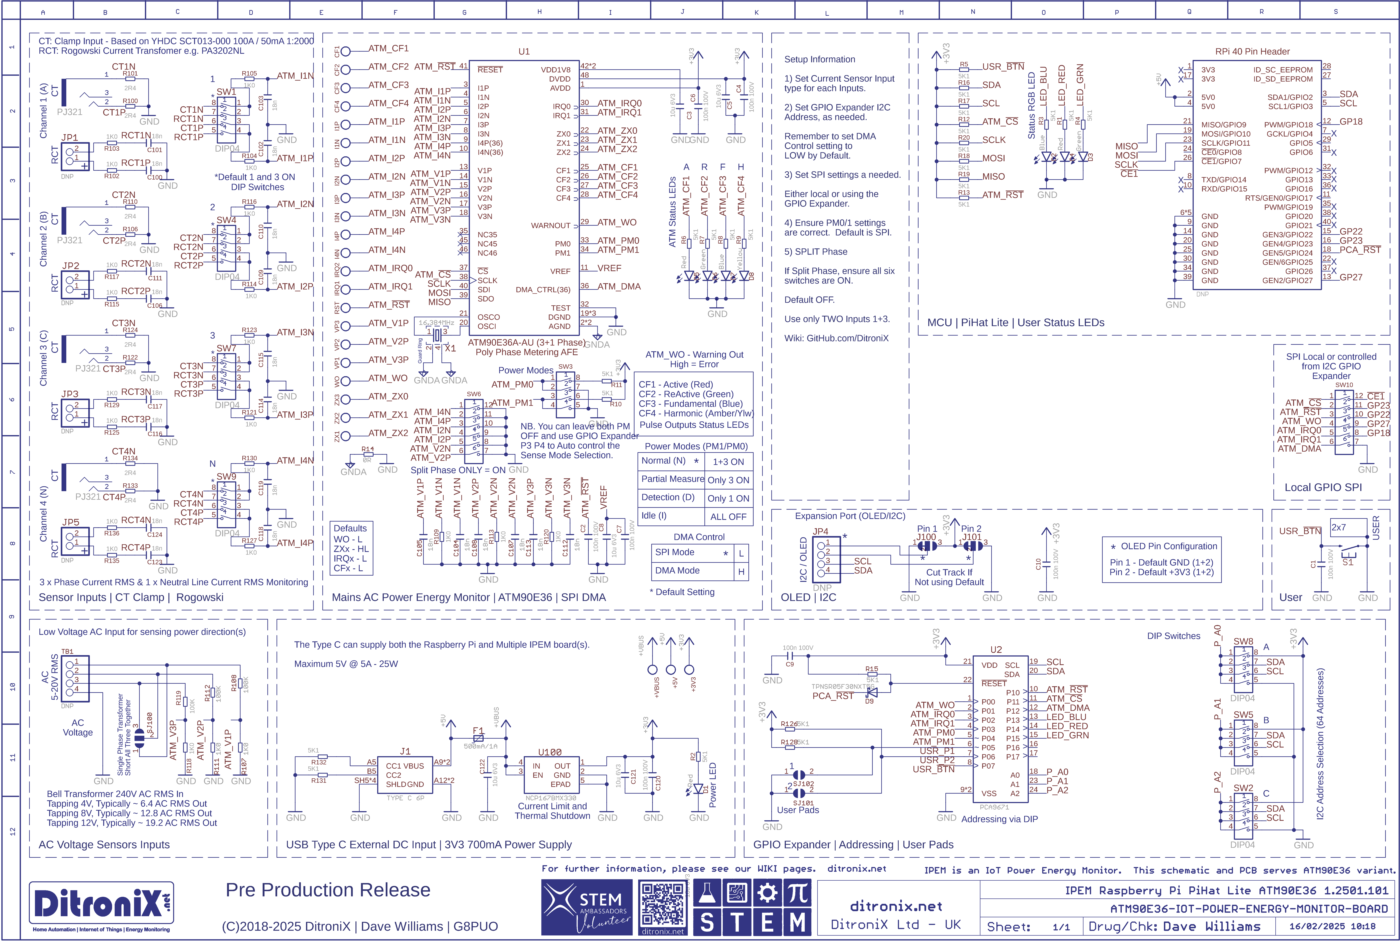
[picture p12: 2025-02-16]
Datasheets and Information/IPEM Raspberry Pi PiHat Lite ATM90E36 1.2501.101 Schematic.png

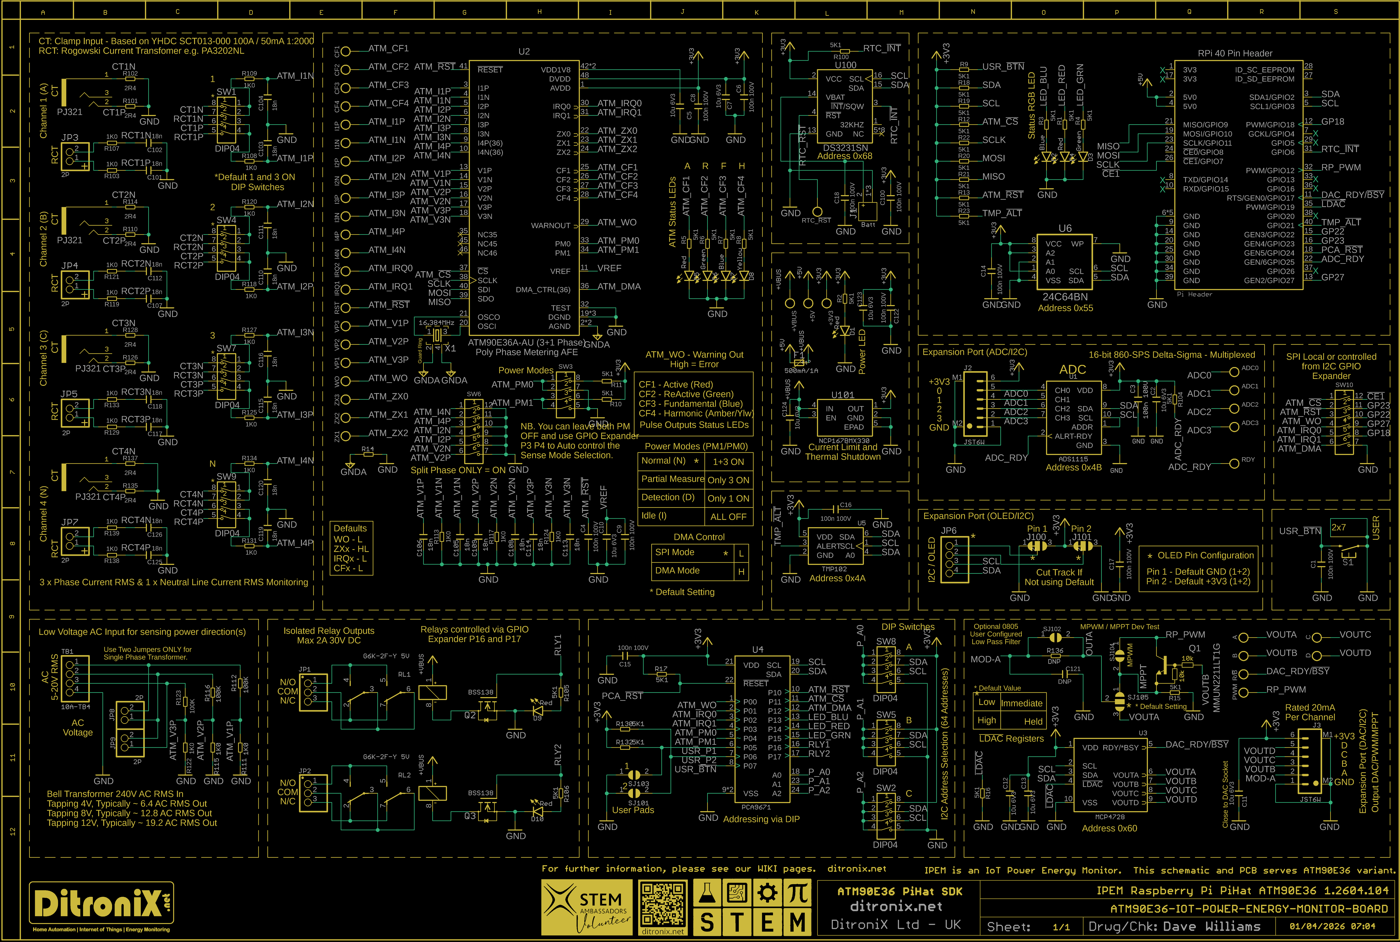
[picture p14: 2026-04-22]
Datasheets and Information/IPEM Raspberry Pi PiHat ATM90E36 1.2604.104 Schematic.png

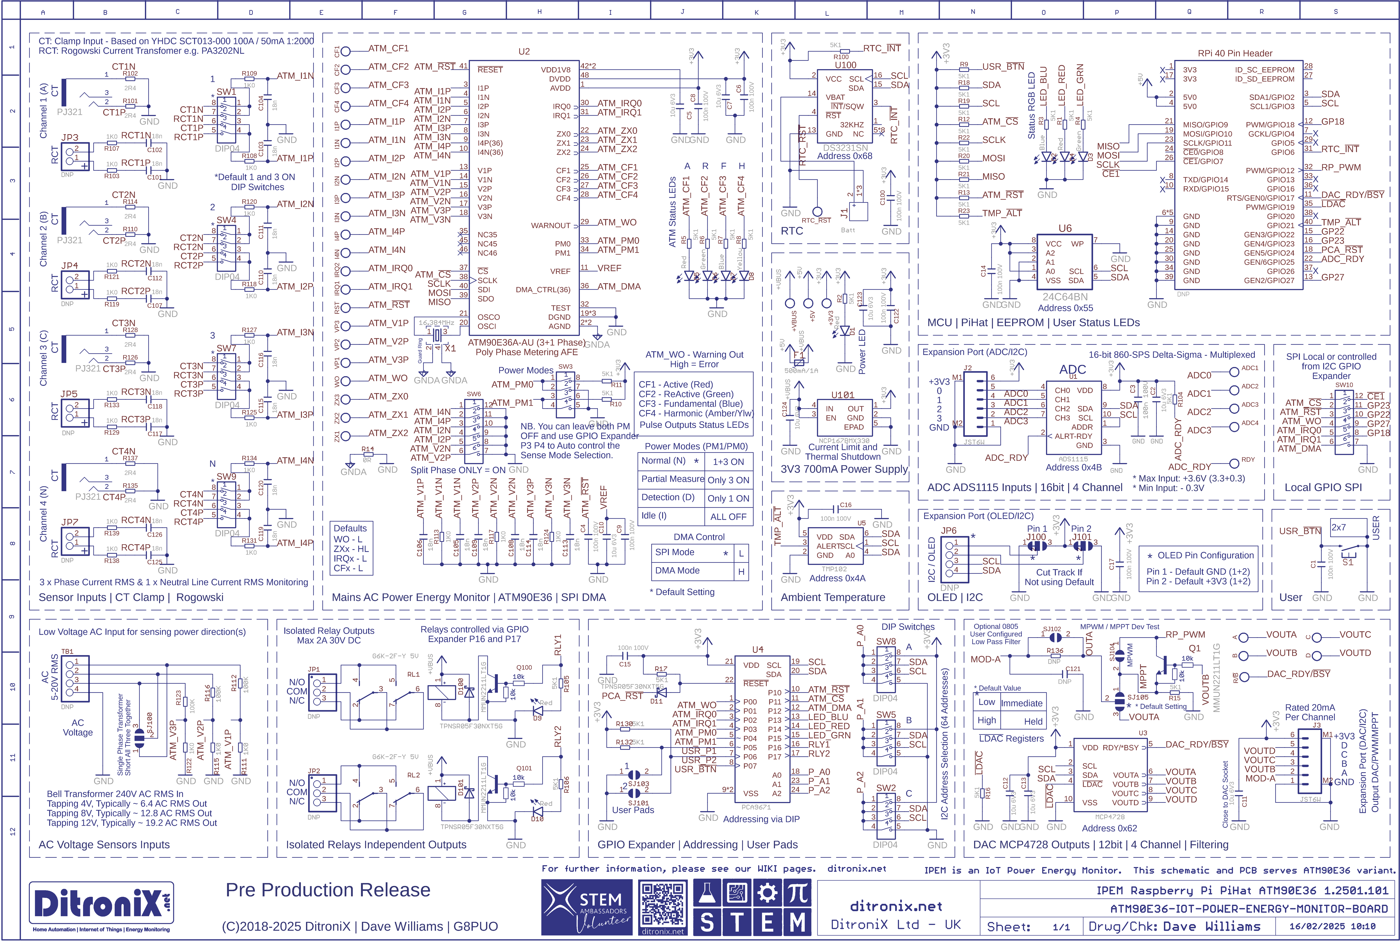
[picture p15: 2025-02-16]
Datasheets and Information/IPEM Raspberry Pi PiHat ATM90E36 1.2501.101 Schematic.png

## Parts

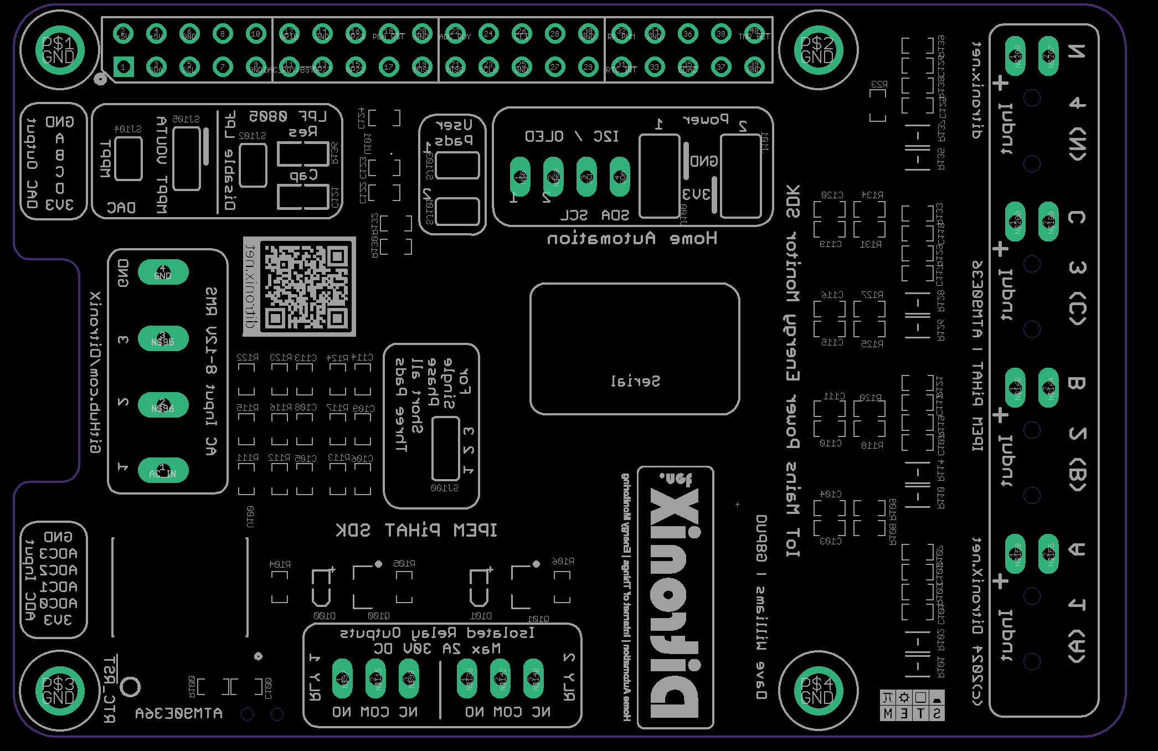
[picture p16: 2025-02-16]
Datasheets and Information/IPEM Raspberry Pi PiHat ATM90E36 1.2501.101 PCB Components Btm.png

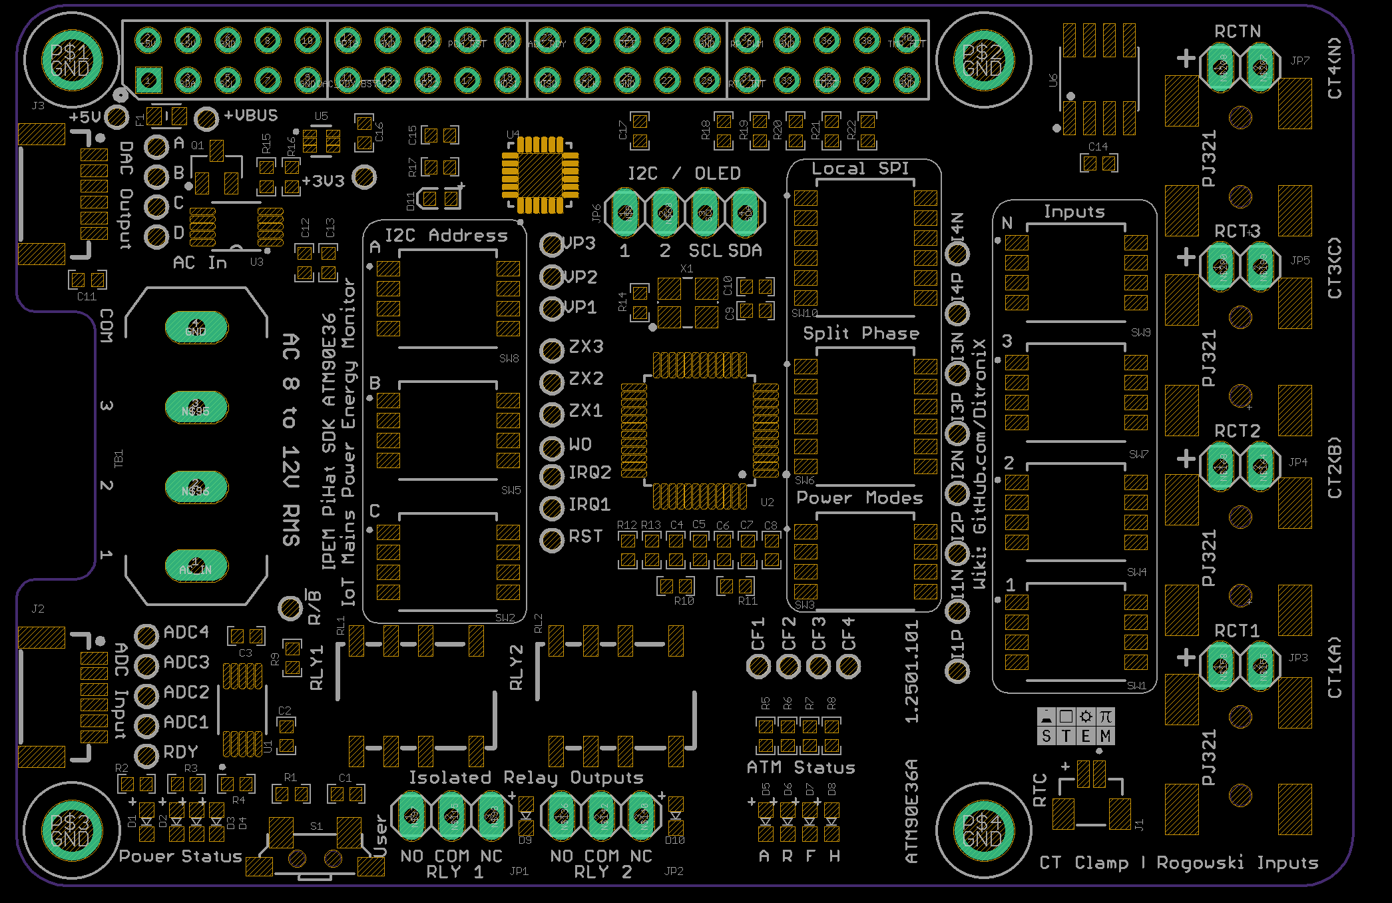
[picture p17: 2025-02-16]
Datasheets and Information/IPEM Raspberry Pi PiHat ATM90E36 1.2501.101 PCB Components Top.png

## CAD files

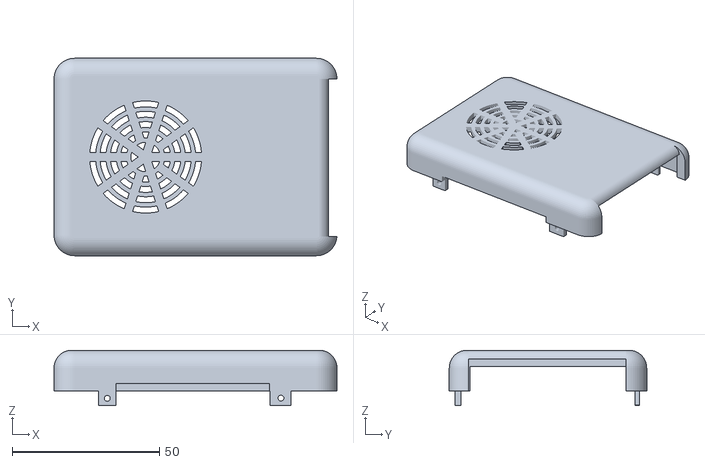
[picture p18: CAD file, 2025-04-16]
Enclosure 3D/Top.stl
96.0 x 67.0 x 18.8

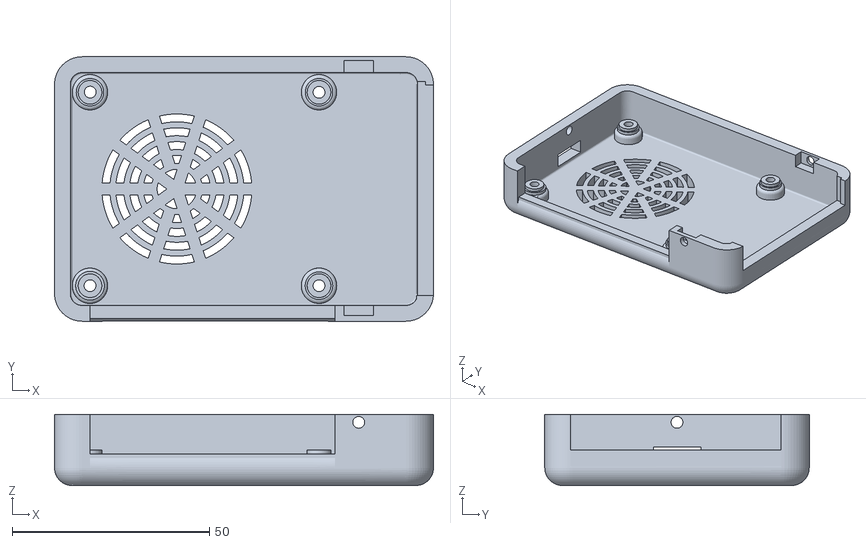
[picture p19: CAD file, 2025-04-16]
Enclosure 3D/Base.stl
96.0 x 67.0 x 18.0

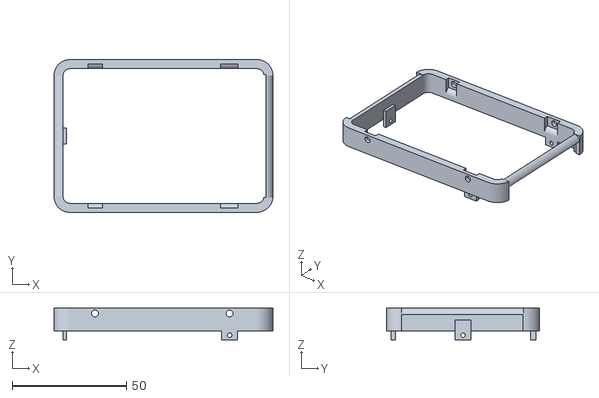
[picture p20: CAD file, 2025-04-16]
Enclosure 3D/1st_Spacer.stl
96.0 x 67.0 x 14.0

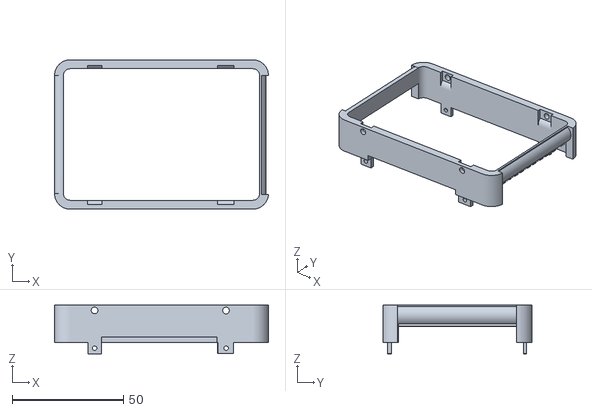
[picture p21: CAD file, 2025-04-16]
Enclosure 3D/2nd_Level.stl
96.0 x 67.0 x 21.9

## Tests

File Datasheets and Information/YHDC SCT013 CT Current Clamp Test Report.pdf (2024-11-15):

## Yhdc SCT-013-000 Current Transformer

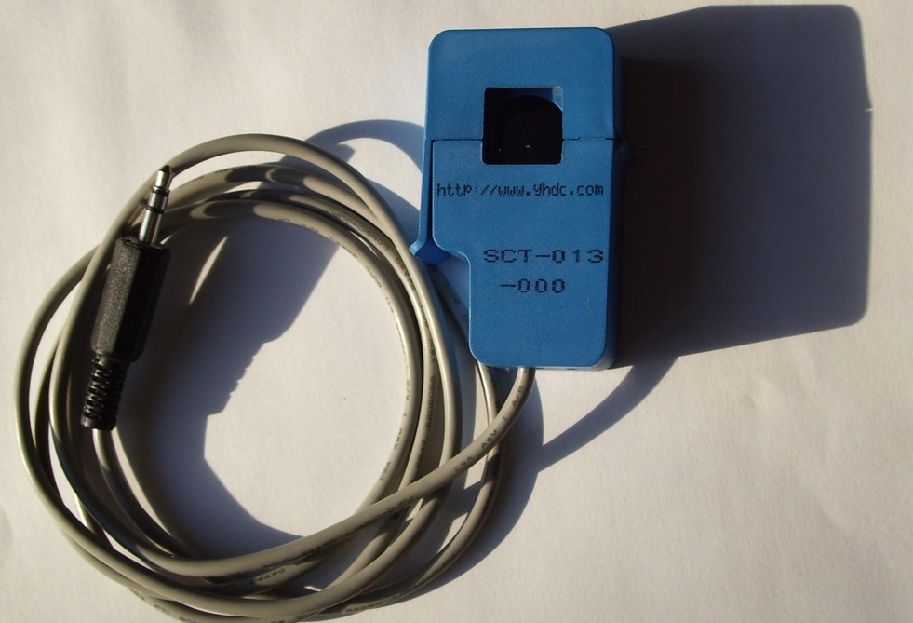
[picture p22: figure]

## A Report on the properties of the Yhdc Current Transformer and its suitability for use with the

OpenEnergy monitor.

by
Robert Wall B.Sc., C.Eng., MIEE.

Issue 6
18 March, 2014

Synopsis
The Yhdc current transformer is manufactured by Beijing YaoHuadechang Electronic Co., Ltd and factored by Seeed Studio of Shenzhen, China (www.seeedstudio.com) as Non-invasive AC current sensor (100A max), Model SCT-013-000, SKU THM105C4B.
It has no internal burden resistor, but zener diodes limit the output voltage in the event of accidental disconnection from the burden. It is capable of developing sufficient voltage to fully drive a 5 V input.

Test Rig

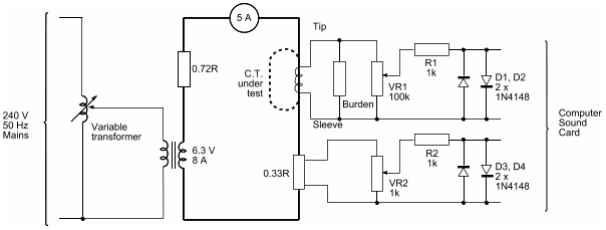
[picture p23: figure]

For test currents up to 150 A, the CT primary consists of from 1 to 30 passes of insulated 16/0.2mm wire, and the majority of tests were made at 5 A – thus the primary current seen by the CT could be adjusted in steps of 5 A by enclosing a variable number of turns inside the core. For saturation tests up to 250 A, the primary consists of 50 passes of enamelled copper wire, the current being adjusted in this case.

(Note: The current exceeds the rating of the wire used for the primary, but as the coil is loosely bunched except where it passes through the transformer core, and because each test is of relatively short duration, heating is not a problem).
The primary current was monitored by the 0.33Ω shunt. The potentiometers, current limiting resistor and diodes in both the shunt and the CT outputs are to protect the computer sound card from over-voltage and switching transients, the potentiometers were adjusted such that the voltage did not exceed 400 mV peak and at this voltage, the diodes did not affect the shape of the monitored waveform.
When the shape of the waveform was of interest, the primary current and CT voltage waveform were recorded using a software oscilloscope (Soundcard Oscilloscope from http://www.zeitnitz.de/Christian/scope_en) and the recorded waveform imported into a spreadsheet and subsequently calibrated against the actual voltage read either by a multimeter or a real oscilloscope connected directly across the CT output.
Since first compiling this report in early 2012, YHDC appears to have changed the core material of the transformer, and a more sensitive and hopefully more accurate technique for measuring the phase error has been developed. For this issue, the two original samples of current transformer have been measured again, and results of phase measurements from a third sample taken from a recent batch have been added.

The Yhdc Current Transformer

Internal Components.

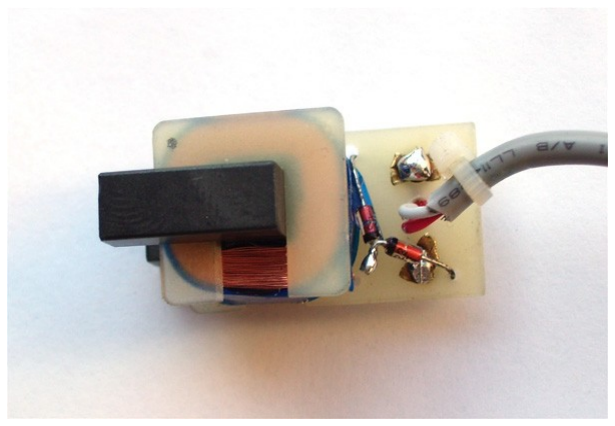
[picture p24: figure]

Circuit Diagram.

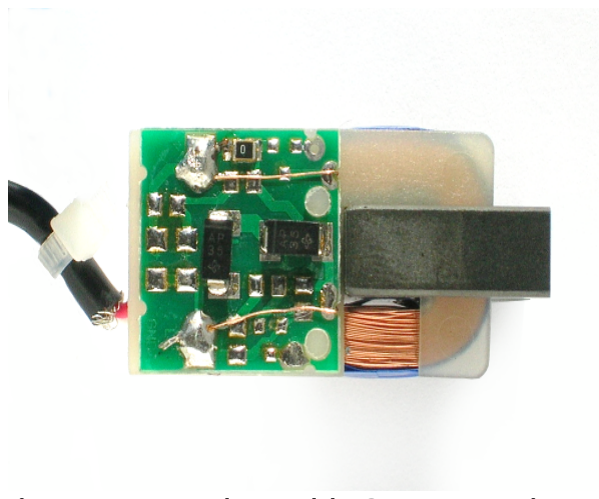
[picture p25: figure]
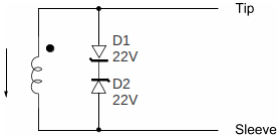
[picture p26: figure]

The current arrow represents current flowing out of the face of the transformer labelled “SCT-013-000”, then the plug tip is positive with respect to the sleeve.
The ring of the plug is not connected.
The purpose of the two 22 V zener diodes is to limit the voltage that may appear on the plug and across the windings to a safe value should the transformer be unplugged from the transmitter/instrument and the burden whilst the primary is energised.
Note: The output of the recent versions is clipped at ± 7.5 V. In the absence of a burden resistor, recovery from clipping is accompanied by H.F. ringing.
Tests
The following tests were conducted:
1. Check the ratio
2. Establish the useful range
3. Establish the effect of burden resistance
4. Establish the phase error
5. Establish the frequency response
6. Check operation with no external burden
7. Establish the maximum output when saturated
(Early model with wire-ended diodes) | (Recent version with SMT parts)

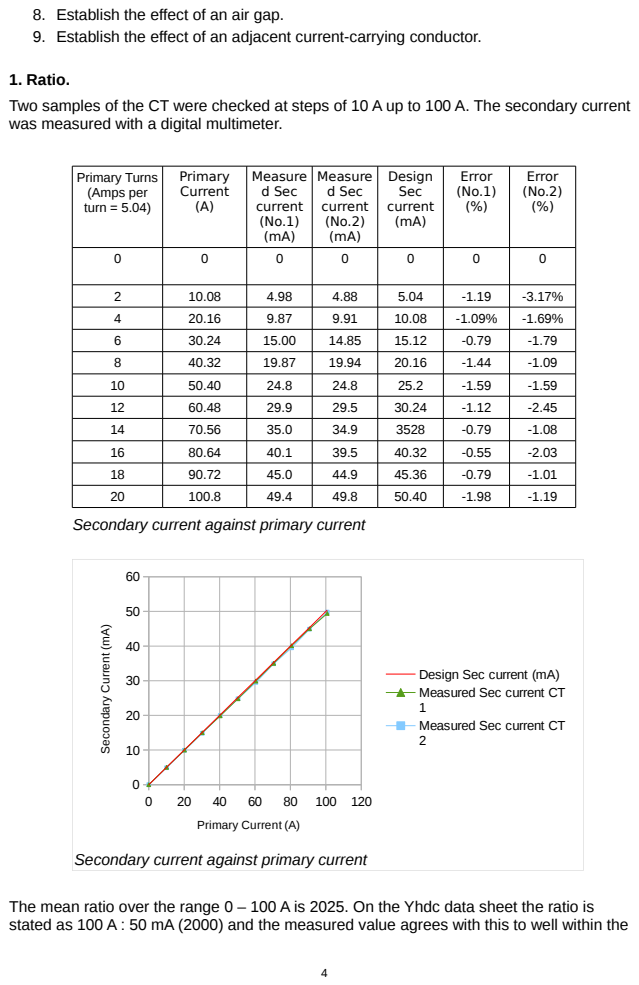
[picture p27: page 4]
Primary Current (A); Secondary Current (m

8. Establish the effect of an air gap.
9. Establish the effect of an adjacent current-carrying conductor.

1. Ratio.
Two samples of the CT were checked at steps of 10 A up to 100 A. The secondary current
was measured with a digital multimeter.

Primary Turns (Amps per turn = 5.04) | Primary Current (A) | Measure d Sec current (No.1) (mA) | Measure d Sec current (No.2) (mA) | Design Sec current (mA) | Error (No.1) (%) | Error (No.2) (%)

2 | 10.08 | 4.98 | 4.88 | 5.04 | -1.19 | -3.17%
4 | 20.16 | 9.87 | 9.91 | 10.08 | -1.09% | -1.69%
6 | 30.24 | 15.00 | 14.85 | 15.12 | -0.79 | -1.79
8 | 40.32 | 19.87 | 19.94 | 20.16 | -1.44 | -1.09
10 | 50.40 | 24.8 | 24.8 | 25.2 | -1.59 | -1.59
12 | 60.48 | 29.9 | 29.5 | 30.24 | -1.12 | -2.45
14 | 70.56 | 35.0 | 34.9 | 3528 | -0.79 | -1.08
16 | 80.64 | 40.1 | 39.5 | 40.32 | -0.55 | -2.03
18 | 90.72 | 45.0 | 44.9 | 45.36 | -0.79 | -1.01
20 | 100.8 | 49.4 | 49.8 | 50.40 | -1.98 | -1.19

Secondary current against primary current

Design Sec current (mA)
Measured Sec current CT

The mean ratio over the range 0 – 100 A is 2025. On the Yhdc data sheet the ratio is
stated as 100 A : 50 mA (2000) and the measured value agrees with this to well within the

limits of uncertainty in the measurement. A unit from an earlier batch was measured at 1854, which is not within the tolerance that should be expected. The value of 100 A : 33 mA (3030) on the Seeedstudio website is clearly an error.
Measurement errors.
The primary current was set on a moving iron ammeter that had been checked against the multimeter. An indicated 5 A measured 5.04 A and this error was accounted for in the measurements. Measuring 5 A, the multimeter used has an accuracy of ±(3% + 10 digits), or 5%. On the mA ranges used to measure the secondary current, the accuracy is ±(1.5% + 5 digits), or between 2.4% and 3.2% depending on the reading. Therefore the total uncertainty in the ratio measurement is around 7.5 – 8.5%.
2. Useful Range.
Saturation is just starting at 100 A, therefore this confirms the maximum current rating. However, the transformer will still give reasonably accurate results even when subjected to a moderate overload.
3. Effect of burden resistance.
As the burden resistance is increased, an increased voltage will be developed across the burden and eventually the output waveform becomes distorted as the core saturates. The variable transformer introduced a flattening of the peak of the current waveform, giving a residual distortion of 2.5%. The value of resistance to give 5% total distortion (at which point the distortion was starting to increase noticeably with increasing resistance), and the voltage at which this occurred, was measured.

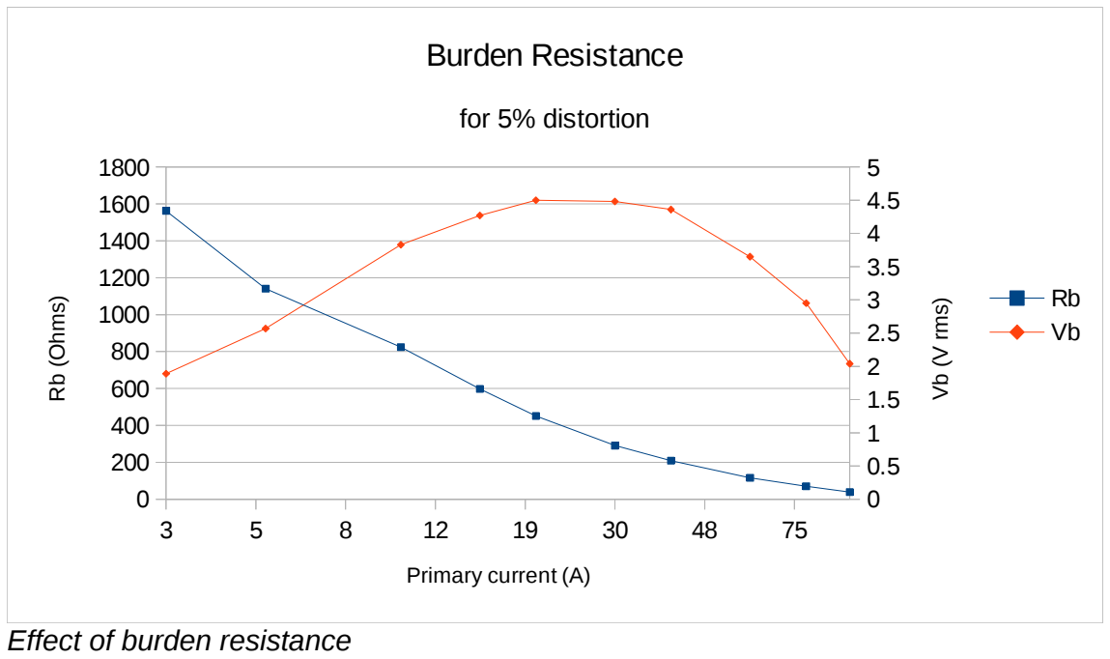
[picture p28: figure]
Effect of burden resistance; Burden Resistance; for 5% distortion; Primary current (A); Rb (Ohms); Vb (V rms)

At any maximum current ( > 5 A ), the resistance at which 5% total distortion occurred was greater than the value necessary to give 5 V peak-peak across the burden resistor, hence saturation poses no limit to the choice of value for the burden resistor.

4. Phase error.
The phase error was measured for 2 values of burden resistor. The values chosen were 18 Ω, the value used in the emonTx Version 2, and 120 Ω which is the value used for the high sensitivity input of the emonTx Version 3.
No.1 & No.2 are the two measured earlier, and No.3 is from a recent batch. No.3 shows a noticeably smaller error that also varies less with current for both burden values. But a note of caution is due with regard to the values at and below 100 mA primary current where noise and pickup were interfering with the measurements, and these cannot therefore be regarded as reliable.

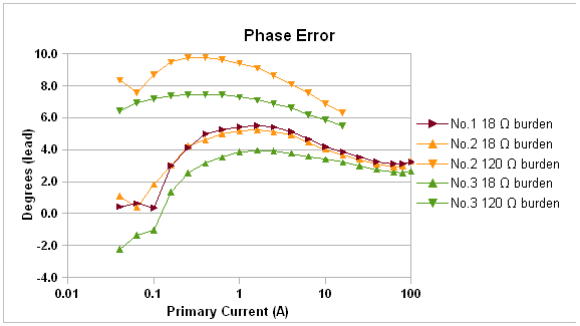
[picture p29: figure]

5. Frequency Response.
The frequency response was checked at a primary current of 30 A and a burden resistance of 39 Ohms. The phase error remained below 1 degree and amplitude error remained below 1% up to the 13th harmonic of line frequency (650 Hz). At 1.5 kHz the amplitude error remained below 1% whilst the phase error had increased to 5 degrees. At 2.5 kHz the amplitude error had risen to 3% whilst the phase error had increased to 10 degrees. These errors are insignificant.
6. Operation without an external burden.
When operated without an external burden, the core quickly saturates. The protective zener diodes conduct at 22 V and this corresponds to a primary current of about 18.3 A. The diodes are not intended to nor will they protect the input circuitry of the Arduino processor and this voltage would without doubt seriously damage or destroy the Arduino chip.

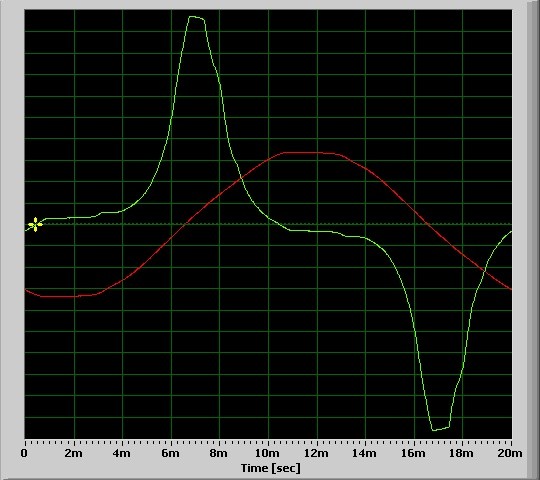
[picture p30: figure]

(The green trace is voltage, the red trace is current, the flattening is caused by large numbers of rectifier loads. Note: the vertical scale is uncalibrated).
7. Maximum output in saturation.
In order to determine the effect of a fault in the primary circuit downstream of the CT, the transformer was driven well into saturation and the output current recorded.

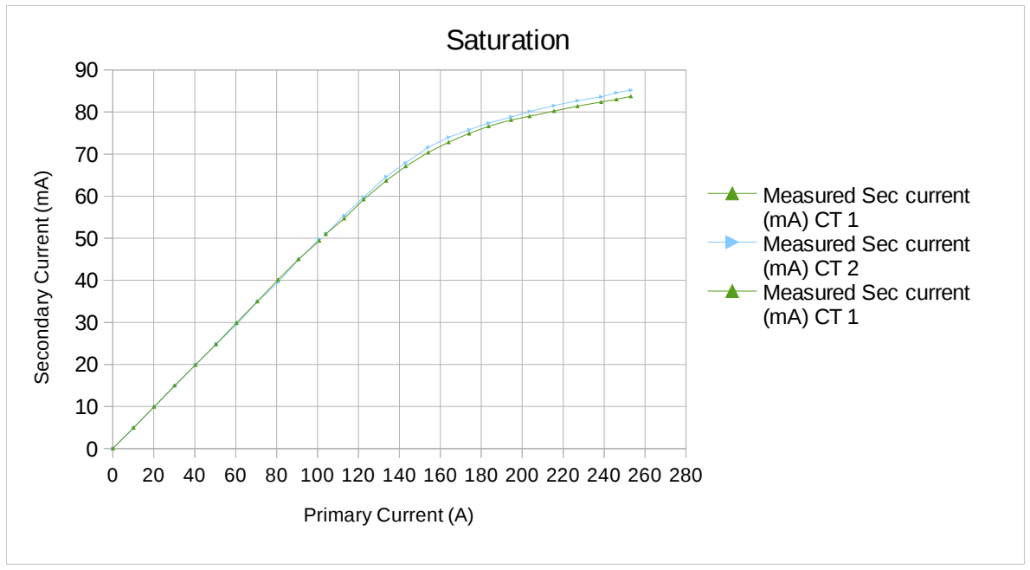
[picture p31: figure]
Saturation; Measured Sec current (mA) CT 1 Measured Sec current (mA) CT 2 Measured Sec current (mA) CT 1; Primary Current (A); Secondary Current (m

The secondary current waveform suffered increasing distortion above 100 A (as would be expected) and the values of secondary current in the graph above are rectified average value scaled to rms.

0 20 40 60 80 100 120 140 160 180 200 220 240 260 280


(The primary current is the green trace, burden voltage is the red trace. The burden voltage at 250 A is 5.2 V p-p)

8. Effect of an air gap.
Introducing an air gap of 0.1 mm in one side of the core caused the secondary current to fall by 7%.
9. Effect of an adjacent current-carrying conductor.
To measure this, a large coil of 20 turns carrying 5 A, oriented so as to simulate a parallel conductor carrying 100 A, was used. The current transformer under test was outside the coil. The equivalent current is the current that the CT would have measured in a conductor passing through the CT.
Distance | Equivalent Current
Touching | 160 mA
20 mm | 110 mA
50 mm | 44 mA
100 mm | 15 mA

Conclusions
The Yhdc current transformer is suitable for use with the OpenEnergy emonTx. It can develop sufficient voltage to fully utilise the resolution of the Arduino's analogue input, and waveform distortion due to saturation at this secondary voltage is negligible for normal purposes. The maximum phase error of 4º from the latest batch with the 18 Ω burden is insignificant (representing a power factor error of less than 0.0025 at unity power factor), but the error of nearly 10º with a 120 Ω burden could be troublesome with low current loads having a poor power factor where this input is most likely to be used.
15 Ω burden, 100 A | 15 Ω burden, 250 A

Changes
Issue 1. 3rd February, 2012
Issue 2. Frequency Response added, 12th February, 2012.
Issue 3. Ratio & saturation data was from one early sample CT, max output in saturation, air gap & appendix added, 23rd February, 2012
Issue 4. New graph for Phase Error (using new batch CT). 3rd March 2012.
Issue 5. New graph for Phase Error and latest batch CT No.3 added. 21st December 2013. Issue 6. Measurements of effect of adjacent conductor added. 18th March 2014.

Appendix
Measurements on non-sinusoidal waveforms.

Most budget multimeters measure the rectified average value of an alternating wave, then the reading is scaled to display the root mean square (rms) value assuming the shape of the wave to be a sinusoid. (The rms value is the value of a direct voltage or current that would give the same heating effect in a purely resistive load).
For many purposes, this approach is entirely adequate, but where the wave shape departs from the sinusoid, this has to be taken into account. When the shape departs markedly from the sinusoid, the difference can be large.
The software oscilloscope used to capture the illustrations above has the capability to export the data points to a text file; that file can then be imported into a spreadsheet for processing. Taking that approach, these values were calculated for the
“15 Ω burden, 250 A” waves:
Calculation | Current (divisions) | Burden Voltage (divisions)
Peak-peak | 14.47 | 6.41
Rectified average (measured value) | 4.62 | 1.30
Rectified average x 1.11 (displayed value) | 5.13 | 1.45
rms | 5.16 | 1.66

The multiplier 1.11 is the 'form factor' for a sine wave. The shape of the current wave is quite close to a sine wave, so the true rms value (5.16) is very close to the value that a budget meter would indicate (5.13 – reading 0.6% low). That is not true for the burden voltage – the meter would read 12.6% low.
The situation is even worse if the displayed value is used to calculate the peak-peak value. The true peak-peak burden voltage is 6.41. Taking the average voltage as measured with a budget meter, multiplied (internally) by 1.11, and then taking that displayed value (1.45) and multiplying by 2√2 to give the peak-peak value assuming a sine wave gives the value of 4.10. The calculated value is low by 36%, a significant error. The form factor for the burden voltage wave turns out to be 1.28.
(Note that even a true rms meter will only calculate the correct value over a limited range of form factors).

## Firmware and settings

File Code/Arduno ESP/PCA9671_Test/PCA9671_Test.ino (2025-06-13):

/*
  Dave Williams, DitroniX 2019-2025 (ditronix.net)

  Example Code, to demonstrate and test the ESPuno Pi Zero, PCA9671 Random GPIO Test

  Further information, details and examples can be found on our website and also GitHub wiki pages:
  * ditronix.net
  * github.com/DitroniX
  * github.com/DitroniX/ESPuno-Pi-Zero_WiFi-BT-Zigbee-Thread-60V
  * github.com/DitroniX/ESPuno-Pi-Zero_WiFi-BT-Zigbee-Thread-60V/wiki
  * hackster.io/DitroniX/espuno-pi-zero-wifi-bt-zigbee-thread-60v-69ef92
  * kickstarter.com/projects/ditronix/espuno-pi-zero

  This test code is OPEN SOURCE and formatted for easier viewing.  Although is is not intended for real world use, it may be freely used, or modified as needed.
  It is distributed on an "AS IS" BASIS, WITHOUT WARRANTIES OR CONDITIONS OF ANY KIND, either express or implied.

  For board configuration, see https://github.com/DitroniX/ESPuno-Pi-Zero_WiFi-BT-Zigbee-Thread-60V/wiki/Arduino-IDE

  Further information, details and examples can be found on our website wiki pages ditronix.net/wiki and also github.com/DitroniX
*/

// Libraries
#include "PCA9671.h"  // https://github.com/RobTillaart/PCA9671

// **************** USER VARIABLES / DEFINES / STATIC / STRUCTURES / CONSTANTS ****************

#define PCA_Address 0x20  // Default I2C address with no switches or solder pads set

PCA9671 PCA(PCA_Address);

// Define I2C (Expansion Port)
#define I2C_SDA 6
#define I2C_SCL 7

uint16_t Pin;

// **************** FUNCTIONS AND ROUTINES ****************

// Force Raw Software Reset
void Force_Raw_Reset() {
  Wire.beginTransmission(PCA_Address);
  Wire.write(0x00);
  Wire.write(0x06);
  Wire.endTransmission();
}

// Random GPIO States
void TestGPIO() {

  // // Write Pin States Sequentially
  for (Pin = 0; Pin < 16; Pin++) {
    PCA.toggle(Pin);
    delay(250);
  }
  delay(2000);

  // Random GPIO States
  Pin = random(16);
  PCA.toggle(Pin);
  delay(2000);
}

// **************** SETUP ****************
void setup() {

  // Stabalise
  delay(250);

  // Initialise UART
  Serial.begin(115200, SERIAL_8N1);  //115200
  while (!Serial)
    ;
  Serial.println("");

  Serial.println(__FILE__);
  Serial.print("PCA9671_LIB_VERSION:\t");
  Serial.println(PCA9671_LIB_VERSION);
  Serial.println();

  // Initialize I2C
  Wire.begin(I2C_SDA, I2C_SCL);

  Serial.println("ESPuno Zero Configured...");

  // Optional Setting as an example
  Force_Raw_Reset();

  PCA.begin();
}

// **************** LOOP ****************
void loop() {

  TestGPIO();

  delay(250);
}

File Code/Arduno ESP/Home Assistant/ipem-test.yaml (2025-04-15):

# Work in Progress. Not Complete (Based on IPEM)

esphome:
  name: ipec-test
  friendly_name: IPEM Test
  on_boot:
    priority: 100 # Highest priority, ensures light turns on without delay.
    then:
      - output.turn_on: gpio_d1
      - output.turn_on: gpio_d2

substitutions:
  default_gain_voltage: '38800'
  default_gain_ct: '38500'
  default_pga_gain: 4X
  default_interval_time: 1s  

esp32:
  board: esp32dev
  framework:
    type: arduino

# Enable logging
logger:

# Enable Home Assistant API
api:
  encryption:
    key: "##"

ota:
  - platform: esphome
    password: !secret ipec_test_ota_password

wifi:
  ssid: !secret wifi_ssid
  password: !secret wifi_password

  # Enable fallback hotspot (captive portal) in case wifi connection fails
  ap:
    ssid: "##"
    password: !secret ipec_test_ap_password

captive_portal:

output:
  - platform: gpio
    pin: GPIO04
    id: gpio_d1

  - platform: gpio
    pin: GPIO15
    id: gpio_d2

status_led:
  pin: GPIO02

font:
  - file: 'fonts/Arial.ttf'
    id: font8
    size: 14

i2c:
  sda: 21
  scl: 22
  scan: true
  id: bus_a

display:
  - platform: ssd1306_i2c
    id: i2cdisplay
    model: "SSD1306 128x32"
    #reset_pin: D0
    address: 0x3C
    pages:
      - id: page1
        lambda: |-
          it.printf(0, 0, id(font8), TextAlign::TOP_LEFT, "CT1 %.2fW", id(CT1CURR).state);
      - id: page2
        lambda: |-
          it.printf(0, 0, id(font8), TextAlign::TOP_LEFT, "CT2 %.2fW", id(CT2CURR).state);
      - id: page3
        lambda: |-
          it.printf(0, 0, id(font8), TextAlign::TOP_LEFT, "CT3 %.2fW", id(CT3CURR).state);

interval:
  - interval: 5s
    then:
      - display.page.show_next: i2cdisplay
      - component.update: i2cdisplay

spi:
  clk_pin: 18
  miso_pin: 19
  mosi_pin: 23

sensor:
  - platform: atm90e32
    id: ctclamp
    cs_pin: 5
    phase_a:
      voltage:
        name: "IPEM Line Voltage"
      current:
        name: "IPEM CT1 Current"
      power:
        name: "IPEM Active Power CT1"
        id: CT1CURR
      reactive_power:
        name: "IPEM Reactive Power CT1"
      power_factor:
        name: "IPEM Power Factor CT1"
      gain_voltage: ${default_gain_voltage}
      gain_ct: ${default_gain_ct}
    phase_b:
      current:
        name: "IPEM CT2 Current"
      power:
        name: "IPEM Active Power CT2"
        id: CT2CURR
      reactive_power:
        name: "IPEM Reactive Power CT2"
      power_factor:
        name: "IPEM Power Factor CT2"
      gain_voltage: ${default_gain_voltage}
      gain_ct: ${default_gain_ct}
    phase_c:
      current:
        name: "IPEM CT3 Current"
      power:
        name: "IPEM Active Power CT3"
        id: CT3CURR
      reactive_power:
        name: "IPEM Reactive Power CT3"
      power_factor:
        name: "IPEM Power Factor CT3"
      gain_voltage: ${default_gain_voltage}
      gain_ct: ${default_gain_ct}
    frequency:
      name: "IPEM Line Frequency"
    chip_temperature:
      name: "IPEM Chip Temperature"
    line_frequency: 50Hz
    current_phases: 3
    gain_pga: ${default_pga_gain}
    update_interval: ${default_interval_time}

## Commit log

2024-12-20 Create IPEM Raspberry Pi PiHat ATM90E36 Energy Monitor 1.2412.101 3D.png
2024-12-21 DitroniX.net IPEM Raspberry Pi PiHat Power Energy Monitor Board SDK
2024-12-26 IPEM Raspberry Pi Energy Monitoring Boards
2025-02-02 Stacking Headers with Standoff Fixings
2025-02-02 PCA9671 Addressing DIL Switch Settings
2025-02-09 Create IPEM CT Clamp connected to Consumer Unit Tails.jpg
2025-02-14 Test CTrea added
    Simple C app for testing reading of CT clamps
2025-03-11 DIP Switches
2025-03-11 3D Enclosure Draft 1
2025-03-12 Isolated Relays
2025-03-12 RTC Battery
2025-04-16 3D Enclosure
    [1st_Spacer.stl, 2nd_Level.stl, Base.stl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]
2026-04-22 IPEM Raspberry Pi PiHat ATM90E36 1.2604.104 Schematic
